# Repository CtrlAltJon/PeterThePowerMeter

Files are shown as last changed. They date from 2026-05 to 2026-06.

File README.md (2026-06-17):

# ⚡ Peter The Power Meter
### with ESP8266 and ADS1115

<p align="center">
  <a href="/Images/guide-docs/view2.jpg">
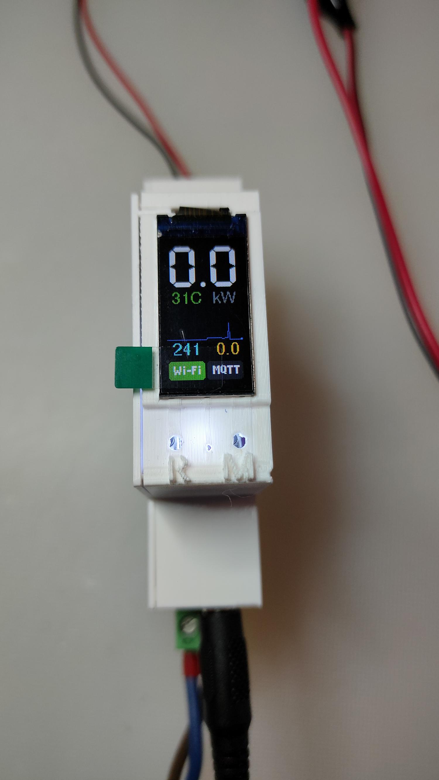
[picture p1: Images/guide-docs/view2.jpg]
Peter the power meter view 2
    
  </a>
</p>

## ⚠️ Disclaimer

> [!CAUTION]
> ### ⚠️ IMPORTANT SAFETY WARNING & DISCLAIMER
> **THIS PROJECT INVOLVES WORKING WITH HIGH VOLTAGE (230VAC). HIGH VOLTAGE CAN CAUSE SEVERE INJURY, ELECTROCUTION, OR DEATH. FIRE HAZARD IS ALSO PRESENT.**
>
> This project is provided "as is", for educational and hobbyist purposes only. By using any part of this project (including hardware designs, PCB layouts, and software), you acknowledge and agree to the following:
>
> * **Assumption of Risk:** You are solely responsible for your own safety and for any damage caused by the assembly, testing, or use of this device.
> * **No Liability:** The author(s) shall not be held liable for any direct or indirect damages, including but not limited to: hardware failure, data loss, property damage (fire, short circuits), personal injury, or death, resulting from the use or misuse of this project.
> * **Assembly & Modification:** Any errors in assembly, soldering (e.g., solder bridges), component selection, firmware modification or others actions are the sole responsibility of the user.
> * **No Warranty:** There is no guarantee regarding the accuracy of measurements, the stability of the software, or the safety of the hardware design for long-term use.
> * **Local Standards:** It is the user's responsibility to ensure that the device complies with local electrical codes and safety regulations.
>
> **IF YOU ARE NOT EXPERIENCED IN WORKING WITH MAINS VOLTAGE, DO NOT ATTEMPT TO BUILD THIS PROJECT.**

## 📜 Revision History
* **00:** First release (30/05/2026)
* **01:** Hardware optimizations and professional safety compliance updates (17/06/2026)
  * **Complete 2.5mm High-Voltage Isolation:** Optimized the High Voltage (HV) layout to strictly enforce a minimum 2.5mm track-to-track clearance across the entire mains section. This includes adding physical PCB isolation slots (milling) between R28, R29, F1, and J3 (pin 2), and shifting transformer TR1 along with adjacent resistors slightly upward to eliminate any tight spacings.
  * **Industrial-Grade Reinforced Insulation:** Preserved the robust **8.0mm isolation barrier** natively designed between the HV and Low Voltage (LV) domains. By combining this wide clearance with the new track-to-track optimizations, the board fully satisfies the strict **Reinforced Insulation** requirements of the **IEC/EN 62368-1** standard (aligning with household and industrial appliance safety regulations like IEC 60335-1 / IEC 60730-1), drastically setting this architecture apart from typical, uncertified DIY designs.
  * **Power Rail & Logic Level Optimization:** Removed 1 pin from connector J11 to eliminate the +5VDC routing to the lateral pcb, successfully migrating the CH340C USB-to-Serial subsystem entirely to a +3.3VDC power rail.
  * **Component Reconfiguration:** Rewired pin 4 (V3) of the CH340C directly to the +3.3VDC rail (mandatory for stable 3.3V operation) while retaining C9 in the layout to act as an active power supply decoupling filter instead of a standard bypass to GND.

## 💡 Design Rationale & Project Overview

### 1.1 System Architecture
This project is a Digital Power Meter designed for real-time energy monitoring with acoustic alarm when a threshold is exceeded. The system is engineered to fit within a standard 1-module DIN rail enclosure (roughly the size of a standard miniature circuit breaker), making it ideal for integration into domestic electrical panels.

*Note: At the moment, the 3D design/CAD file for the DIN enclosure is not available. Contributions regarding the design of a suitable enclosure are highly welcome and would be a valuable addition to this project.*

The system architecture is based on the ESP8266 (ESP-12F) microcontroller, leveraging its Wi-Fi capabilities for IoT integration and an ADS1115 to read voltage and current. For system health, an onboard TFPT1206L1002DV temperature sensor is included to monitor the internal thermal conditions of the enclosure.

For local interaction, the device features a 0.96" color LCD display that provides real-time data visualization and configuration menus. Users can navigate through multiple data pages and perform basic setup tasks using a multi-function physical button. Additionally, the system hosts a built-in Web Server, allowing for advanced remote configuration, firmware updates (OTA), and detailed system management via an intuitive Web UI.

The measurement stage utilizes two primary sensors:
* **Voltage Sensing:** Handled via a dedicated voltage transformer ZMPT107-1 (TR1) for galvanic isolation and safety.
* **Current Sensing:** Implemented using the SCT-013 split-core current transformer (clamp meter).

Both sensors provide a 1VAC sinusoidal output. These signals are conditioned via a voltage divider network and sampled by an ADS1115 16-bit ADC, which communicates with the MCU via the I2C protocol.

### 1.2 Hardware Features & User Interface

<p align="center">
  <a href="/Images/guide-docs/view1.jpg">
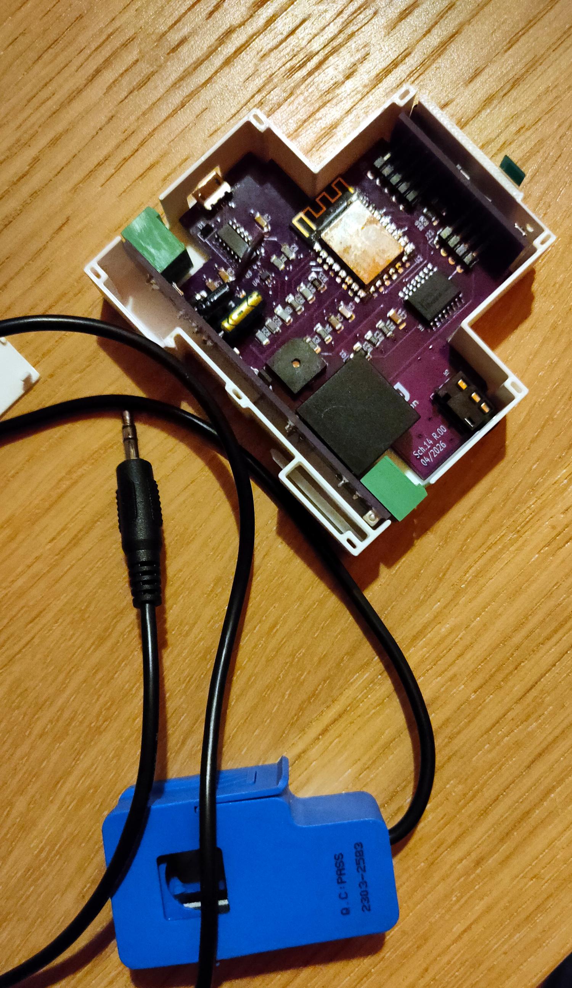
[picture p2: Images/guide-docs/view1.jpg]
Peter the power meter view 1
    
  </a>
</p>

To optimize GPIO usage, a PCF8574 I/O expander is employed for digital signal management and future use. The user interface consists of:
* **Buttons:** A multi-function navigation button (Short press: Page toggle | Long press: Confirm/Action) and a dedicated Pin-hole Hardware Reset button connected directly to Pin 1 (RST) of the ESP8266.
* **Acoustic Feedback:** An active piezoelectric buzzer triggers an audible alarm when a software-defined power threshold is exceeded.
* **Thermal Monitoring:** An onboard TFPT1206L1002DV temperature sensor (PTC thermistor) is integrated into the circuit. This component allows the system to monitor the internal temperature of the enclosure.
* **Display:** A 0.96" Color LCD for local monitoring and basic interaction.
* **Web Server:** A Web User Interface for remote monitoring and full system configuration.

### 1.3 Power Supply & Protection
The device supports 2 power input options and 1 input 230VAC for Voltage reading:

* **Terminal Block (J1):** Accepts a +5VDC regulated supply.

> [!CAUTION]
> **No reverse polarity protection:** This input currently lacks reverse polarity protection; correct orientation is mandatory.

<p align="center">
  <a href="/Images/guide-docs/Guide_J1_Rev-01.png">
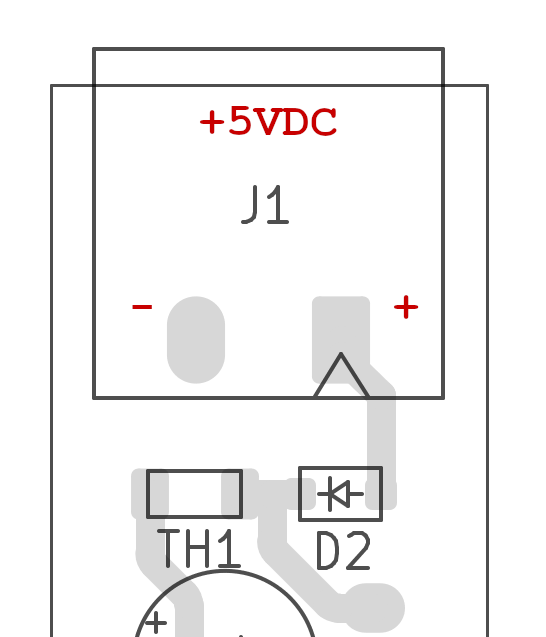
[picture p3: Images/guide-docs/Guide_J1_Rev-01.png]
J1 No reverse polarity protection
    
  </a>
</p>

* **USB Connector (J2):** For secondary power or debugging.
    * *Communication & Debugging:* This interface utilizes a CH340C USB-to-Serial bridge and a UMH3NFHATN transistor pair to communicate with the ESP8266. This setup enables full debugging, serial communication, and firmware programming (automatic reset/bootloader entry).
    * *Safety Feature:* The board implements a dual Schottky diode protection circuit on the positive rails of both J1 and J2. This prevents back-feeding, though it is recommended to disconnect J1 when using USB power.
    * *Overcurrent Protection:* The +5VDC main rail is protected by a MF-NSMF050-2 PTC (Resettable Fuse) rated at 500mA.
* **AC Voltage Input (J3):** High-voltage input for the ZMPT107-1 transformer.
    * *Polarity Recommendation:* Although the transformer operates on AC, it is strictly recommended to respect the Phase (L) and Neutral (N) markings.
    <p align="center">
      <a href="/Images/guide-docs/Guide_J3_Rev-01.png">
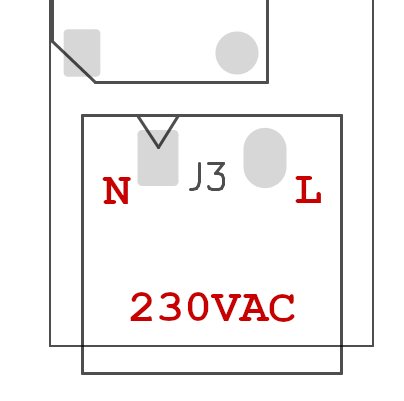
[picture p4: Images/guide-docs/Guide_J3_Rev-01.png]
J3 High-voltage input
        
      </a>
    </p>

    * *Safety Rationale:* The protection fuse is located exclusively on the Phase line. Inverting the polarity would mean that, in the event of a fault or a blown fuse, the Neutral line would be disconnected while the entire internal circuit remains energized (live) through the Phase line. This creates a severe electrocution hazard even when the device appears to be non-functional.
    * *Safety Design:* The circuit features a 250mA T (Slow-blow) fuse placed exclusively on the Phase line. Additionally, the line is equipped with three resistors in series designed to limit the current to 1mA RMS at 230V, providing an essential layer of protection for the sensing stage.

### 1.4 Operational Limits & Grid Compatibility
This device is specifically designed and calibrated for 230VAC/50Hz Phase-Neutral grids (Standard European Grid).

* **Voltage Specificity:** The internal components, including the protection resistors and the ZMPT107-1 transformer ratio, are optimized for 230V. Use with different mains voltages (e.g., 110-120V) may result in inaccurate readings or insufficient signal-to-noise ratio.
* **Frequency Specificity:** The system is tuned for 50Hz operation. While the magnetic components (TR1 and CT) can physically handle 60Hz, the firmware's sampling window and RMS calculation algorithms are optimized for a 20ms period.
* **Warning:** Operation on different grid standards, high-voltage industrial lines, or Phase-to-Phase configurations (without a neutral line) may exceed the safety ratings of the components and the fuse, leading to hardware failure or fire hazard.

## 🌐 2.0 Connectivity & Software Integration
The firmware architecture features a built-in Web Server for real-time monitoring, local configuration, and connections management (Wi-Fi and MQTT). The device natively supports the MQTT protocol for a smart home integration with platforms such as Home Assistant.

### 2.0.1 LCD User Interface (Vertical Orientation)
Navigation is handled via the multi-function button (Short press: Page toggle | Long press: Confirm/Action).

* **Page 1: Real-time Monitor**
    * Power: Current power consumption displayed in kW.
    * Temperature: PCB temperature in °C.
    * Graph: A rolling history graph showing power trends (approx. 1-minute window).
    * Status Badges: Dynamic icons for Wi-Fi connection status and MQTT connection status.
* **Page 2: Power Threshold Configuration**
    * Displays the active alarm threshold (Watts).
    * Allows cyclic adjustment of the new threshold (100W increments) via long-press.
* **Page 3: Voltage Monitoring**
    * Displays the real-time mains voltage (V).
* **Page 4: Acoustic Alarm Settings**
    * Displays and cycles through buzzer modes: Continuous, Slow Intermittent, or Fast Intermittent.
* **Page 5: Save Settings**
    * Summarizes settings. Action: A long-press commits settings to non-volatile memory.
* **Page 6: System Information**
    * Displays network details: Hostname, SSID, IP Address, and Firmware Version.
* **Page 7: System Tools**
    * AP Mode, Reboot device, and Reset (Factory Reset). Requires a long-press with a visual timer-bar.

### 2.0.2 Web Interface & Configuration
The device features a responsive Web UI. Users can connect via browser to the device's IP (visible on LCD page 6).

#### Home Page (Real-Time Dashboard)
* **Connectivity Status:** Dynamic badges for AP Mode, Wi-Fi, and MQTT.
* **Live Telemetry:** Power (W), Voltage (V), Current (A).
* **System Uptime:** Tracks operational time in "Days hh:mm:ss" format.
* **Data Refresh:** Auto-refresh every 10 seconds or manual button.

#### Configuration Page
* **General Settings:** Hostname, Manufacturer, Language (IT/EN), Alarm Threshold, Buzzer Mode.
* **Wi-Fi Setup:** Credentials and IP Assignment (DHCP or Static IP).
* **MQTT Setup (Optional):** Broker IP, Port, and Authentication.
* **Buttons:** Save & Reboot, Reboot, Firmware Update (OTA), Home.

## 🛠️ Manufacturing & Assembly Notes

### 3.0 Hardware Configuration
**ADS1115 I2C Address Selection:** Hardware-defined through two "0-Ohm bridge" resistors: R16 and R17. Only one of these resistors must be populated at a time:
* **R16:** Connects the ADDR pin to +3.3V, ADS1115 Address `0x49`
* **R17:** Connects the ADDR pin to GND, ADS1115 Address `0x48` (Default).

**Safety Design:** To prevent assembly errors, the PCB layout utilizes a shared common pad for both R16 and R17. This physical constraint makes it nearly impossible to populate both resistors simultaneously, effectively protecting the +3.3V rail from a direct short circuit to Ground. However, be careful when assembling.

## Assembly Layout: TOP Layer
<p align="center">
  <a href="/Images/guide-docs/Guide_Assembly-Top_Rev-01.png">
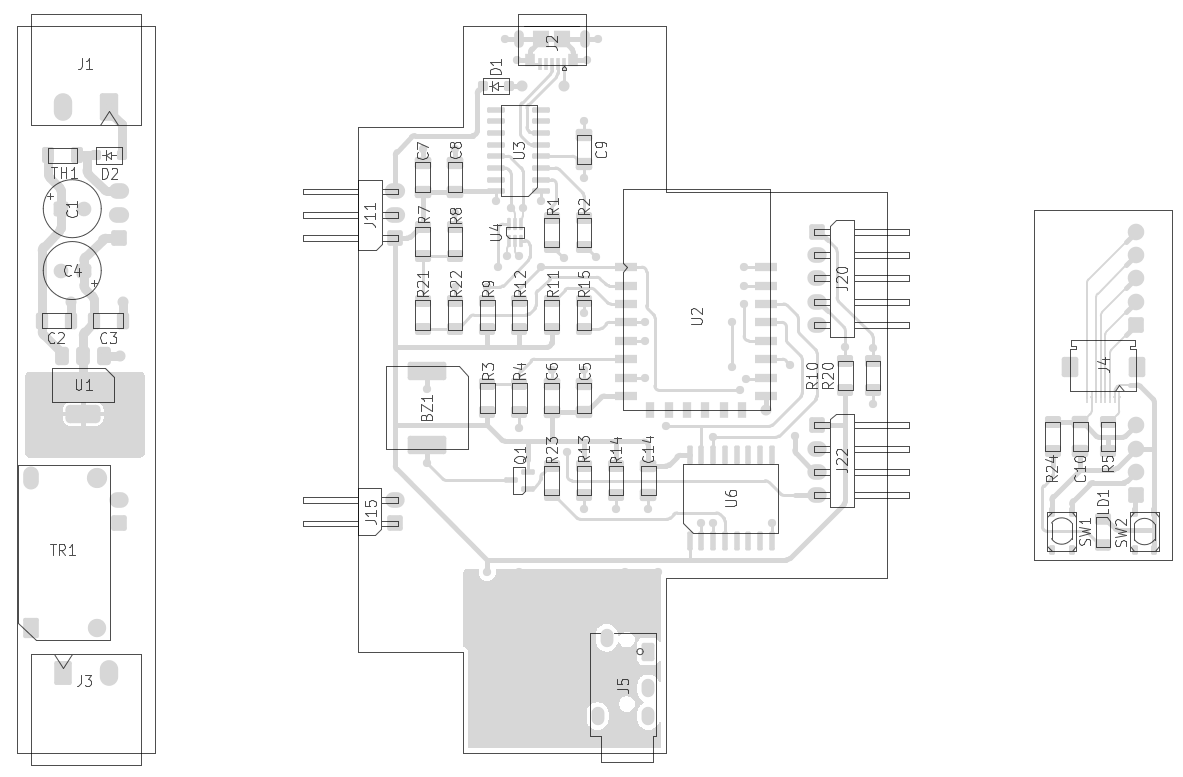
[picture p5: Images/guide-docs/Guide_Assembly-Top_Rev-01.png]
Assembly Layout Top
    
  </a>
</p>

## Assembly Layout: BOTTOM Layer
<p align="center">
  <a href="/Images/guide-docs/Guide_Assembly-Bottom_Rev-01.png">
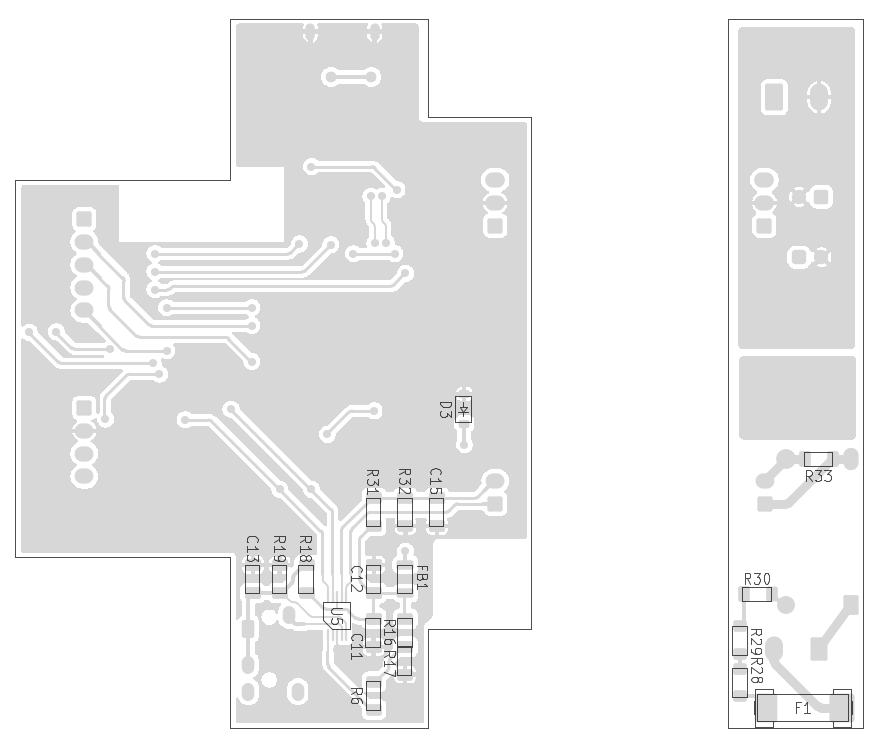
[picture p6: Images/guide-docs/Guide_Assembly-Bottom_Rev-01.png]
Assembly Layout Bottom
    
  </a>
</p>

## Dimensions
<p align="center">
  <a href="/Images/guide-docs/Guide_Dimensions_Rev-01.png">
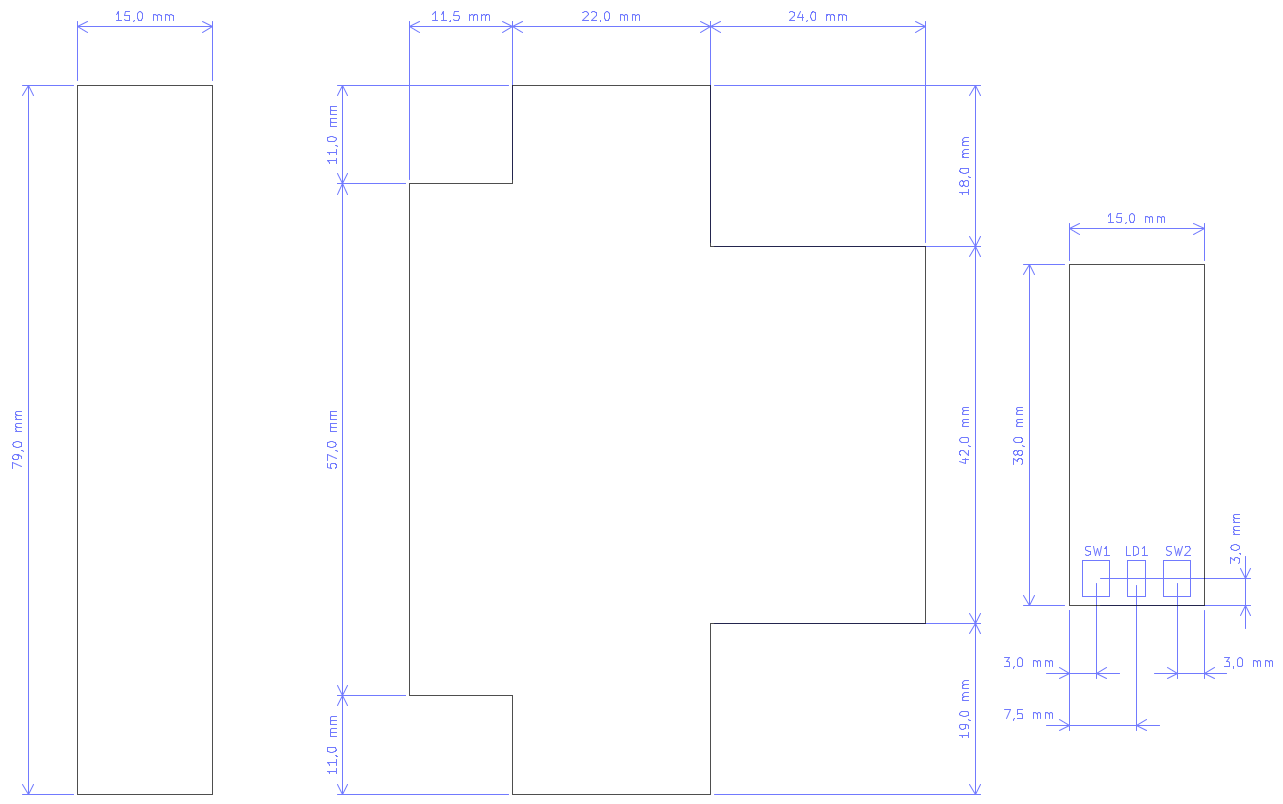
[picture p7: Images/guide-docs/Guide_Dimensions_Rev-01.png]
Dimensions
    
  </a>
</p>

## 💻 4.0 Firmware
Peter The Power Meter has an embedded firmware designed for real-time single-phase energy monitoring. The system samples AC voltage and current waveforms, calculates Root Mean Square (RMS) values and active power consumption, provides a multi-page visual interface on a TFT display, and integrates with home automation systems via the MQTT protocol.

### Technical Specifications
* **Language:** C++ (Standard C++11/14).
* **Framework:** Arduino Core for ESP8266.
* **Development Environment:** PlatformIO.
* **Core Hardware:** Espressif ESP8266 (e.g., Wemos D1 Mini).
* **Data Acquisition:** External ADS1115 16-bit ADC connected via I2C for high-precision differential sampling.
* **Sensor Support:** Current Transformers (SCT-013), Voltage Transformers (ZMPT107-1), and PTC temperature sensors (TFPT1206).

### Key Features
* **High-Speed Sampling & RMS Calculation:** Performs rapid sampling of sinusoidal signals to calculate precise Voltage RMS, Current RMS, and Active Power (W) over a sliding 1-second window.
* **Display Management:** Features a multi-page User Interface on an ST7735 (0.96" TFT) display; includes real-time power trend graphs, connectivity status badges, and system information pages.
* **IoT & Home Automation:**
    * **MQTT Telemetry:** Transmits energy data using a time-weighted average calculated over the publishing interval (default 20s).
    * **Home Assistant Integration:** Fully supports Auto-Discovery, automatically creating sensors and configuration entities (Select/Number) within Home Assistant.
* **Embedded Web Server:** A built-in web portal protected by HTTP Basic Authentication allows users to configure WiFi credentials, MQTT settings, alarm thresholds, and perform fine sensor calibration (offset and scale).
* **Alarm System:** Manages a buzzer via a PCF8574 I/O expander with programmable modes (Continuous, Slow Pulse, Fast Pulse) triggered when power exceeds a user-defined threshold.
* **Reliability & Maintenance:**
    * **Resilient Connectivity:** Implements an exponential backoff strategy for WiFi and MQTT reconnection.
    * **OTA Updates:** Supports Over-The-Air firmware updates through the web interface.
    * **Localization:** Built-in multi-language support (English and Italian) using PROGMEM to optimize RAM usage.

### 4.0.1 Sensor Calibration & Physics Guide (include/config.h)
The following constants define how the raw electrical signals from the sensors are translated into human-readable values (Amps, Volts, Watts).

#### Current Conversion (FACTOR_A_V)
* **Description:** This is the scaling factor for the Current Transformer (CT). It converts the voltage measured by the ADC into RMS Amperes.
* **Formula:** `I_RMS = V_ADC * FACTOR_A_V`.
* **Configuration:** The `FACTOR_A_V` of 25.0f is set based on the characteristics of the SCT-013 current transformer.
* **When to change:**
    1. You replace the SCT-013 with a model that has a different Current/Voltage ratio (e.g., 30A/1V or 100A/50mA).
    2. You add or change an external burden resistor in parallel with the CT output.

#### Voltage Conversion (FACTOR_V_V)
* **Description:** This factor scales the low-voltage signal from the ZMPT107-1 transformer back to the actual grid voltage.
* **Formula:** `V_Grid = V_ADC * FACTOR_V_V`.
* **Configuration:** The `FACTOR_V_V` of 246.0f is derived directly from the ratio of the primary resistance (246KΩ) to the burden resistance (1KΩ).
* **When to change:** If you modify the scaling "divider" (e.g., changing series resistors on the Primary side or the burden resistor on the Secondary side).

#### ADC Precision & Sampling Rate
* **ADC Precision:** `ADS_GAIN` (GAIN_TWO) sets the full-scale range to ±2.048V, with an `ADS_MULTIPLIER` of 0.0000625.
* **Sampling Rate:** 860 Samples Per Second is the maximum stable rate for the ADS1115 and provides high fidelity for power calculations.

#### Noise, Safety, and Temperature
* **CURRENT_NOISE_FLOOR (0.002f):** A software filter that forces the current to 0.0A if the measured voltage is below 2mV.
* **VOLTAGE_MIN_THRESHOLD (50.0f):** If the measured voltage is below 50V, the system assumes the sensor is faulty and falls back to 230V.
* **Temperature Monitoring:** The firmware averages 10 readings (`PTC_AVG_SAMPLES`) to stabilize the PTC sensor data; if the temperature exceeds `TEMP_WARNING_THRESHOLD` (45.0°C), the display text turns RED.

| Constant | Default Value | Unit | Description |
| :--- | :--- | :--- | :--- |
| FACTOR_A_V | 25.0 | A/V | Ratio of Amps per Volt from the CT circuit. |
| FACTOR_V_V | 246.0 | V/V | Ratio of Grid Volts per Volt from the VT circuit. |
| ADS_GAIN | GAIN_TWO | - | Sets ADC input range to ±2.048V. |
| ADS_SPS | 860 | Hz | Samples taken per second from the AC wave. |
| CURRENT_NOISE_FLOOR | 0.002 | V | Minimum voltage to consider a valid current reading. |
| VOLTAGE_MIN_THRESHOLD | 50.0 | V | Voltage below which the system uses a fallback value. |

### 4.0.2 Per-device calibration limits (include/config.h)
These constants define the acceptable range and default values for the calibration parameters stored in EEPROM.

* **Scale Factors:** `CAL_SCALE_DEFAULT` is 1.0f (no correction), with a range between 0.1f and 10.0f.
* **Voltage Offset Limits:** -500.0f to 500.0f Volts.
* **Current Offset Limits:** -100.0f to 100.0f Amperes.
* **Temperature Offset Limits:** -50.0f to 50.0f degrees Celsius.

| Constant | Default/Range | Unit | Description |
| :--- | :--- | :--- | :--- |
| CAL_SCALE_DEFAULT | 1.0f | - | Default multiplicative scale factor. |
| CAL_SCALE_MIN | 0.1f | - | Minimum allowed value for scale factors. |
| CAL_SCALE_MAX | 10.0f | - | Maximum allowed value for scale factors. |
| CAL_OFFSET_V_MIN | -500.0f | V | Minimum allowed voltage offset. |
| CAL_OFFSET_V_MAX | 500.0f | V | Maximum allowed voltage offset. |
| CAL_OFFSET_A_MIN | -100.0f | A | Minimum allowed current offset. |
| CAL_OFFSET_A_MAX | 100.0f | A | Maximum allowed current offset. |
| CAL_OFFSET_TEMP_MIN | -50.0f | °C | Minimum allowed temperature offset. |
| CAL_OFFSET_TEMP_MAX | 50.0f | °C | Maximum allowed temperature offset. |

### 4.0.3 PTC Calibration & Hardware (include/config.h)
The device monitors internal temperature using the TFPT1206 series PTC sensor.

* **PTC_V_SOURCE:** 3.3f (Standard logic voltage).
* **PTC_R_PULLUP:** 33,000 Ω (Fixed resistor R7).
* **ADC Compensation:** Constants `PTC_R_DIVIDER_TOTAL` and `PTC_R_DIVIDER_LOAD` compensate for the voltage divider on the ESP8266 ADC input stage.
* **Sensor Characteristics:** `PTC_NOMINAL_RES` (10,000 Ω at 25°C) and `PTC_COEFF` (0.00411) define the resistance-to-temperature curve.

| Constant | Default Value | Unit | Description |
| :--- | :--- | :--- | :--- |
| PTC_V_SOURCE | 3.3 | V | Logic source voltage for the sensing branch. |
| PTC_R_PULLUP | 33,000 | Ω | Fixed pull-up resistor ($R_7$) in the divider. |
| PTC_NOMINAL_RES | 10,000 | Ω | PTC resistance at 25°C. |
| PTC_COEFF | 0.00411 | - | TCR (Temperature Coefficient) of the sensor. |
| PTC_R_DIVIDER_TOTAL | 100,220 | Ω | ADC input stage total resistance ($R_{21} + R_{22}$). |

## 🤝 Contributing

Contributions, issues, and feature requests are welcome!
Feel free to [open an issue](https://github.com/CtrlAltJon/PeterThePowerMeter/issues) or submit a pull request.

## 🔜 Coming Soon
I am currently in the process of refining and cleaning up the firmware comments to ensure the code is as clear and readable as possible, even though the project is fully functional.
I am also polishing the documentation and preparing additional guides that I'll upload to the repository soon.
Currently seeking help with:
* Enclosure Design: I'm looking for contributors to design a 3D-printable enclosure compatible with a standard 1-module DIN rail format. I think I'll be able to upload at least the STL file soon, but not the project.

## 📝 License

This project is licensed under the MIT License. See the [LICENSE](LICENSE) file for details.

## 👤 Author

CtrlAltJon

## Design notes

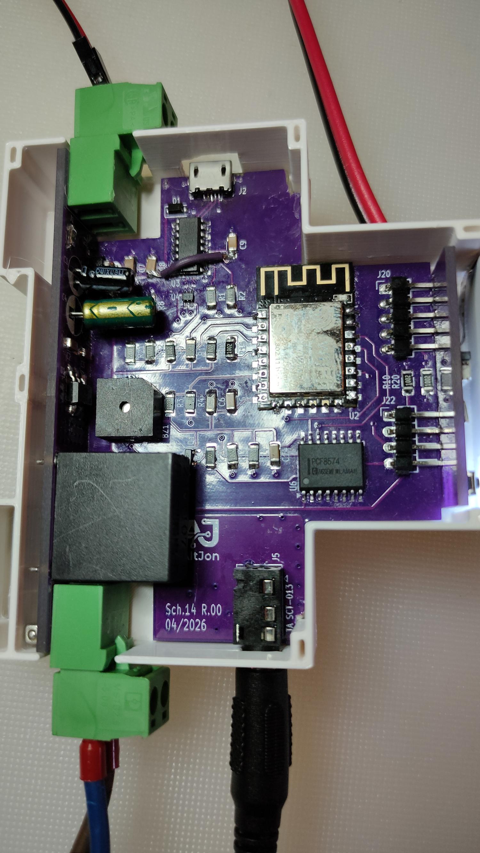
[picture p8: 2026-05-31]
Images/hardware/peter-hw-01.jpg

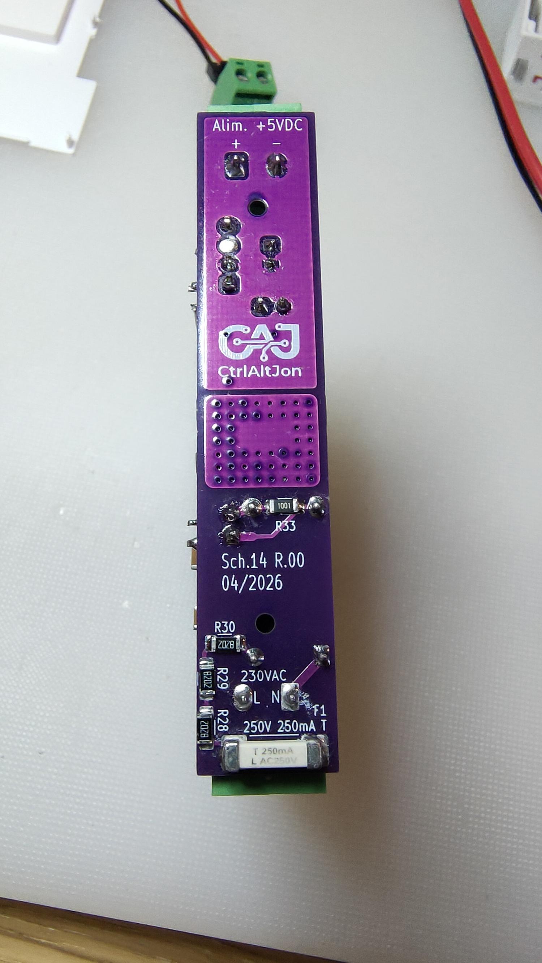
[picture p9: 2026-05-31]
Images/hardware/peter-hw-06.jpg

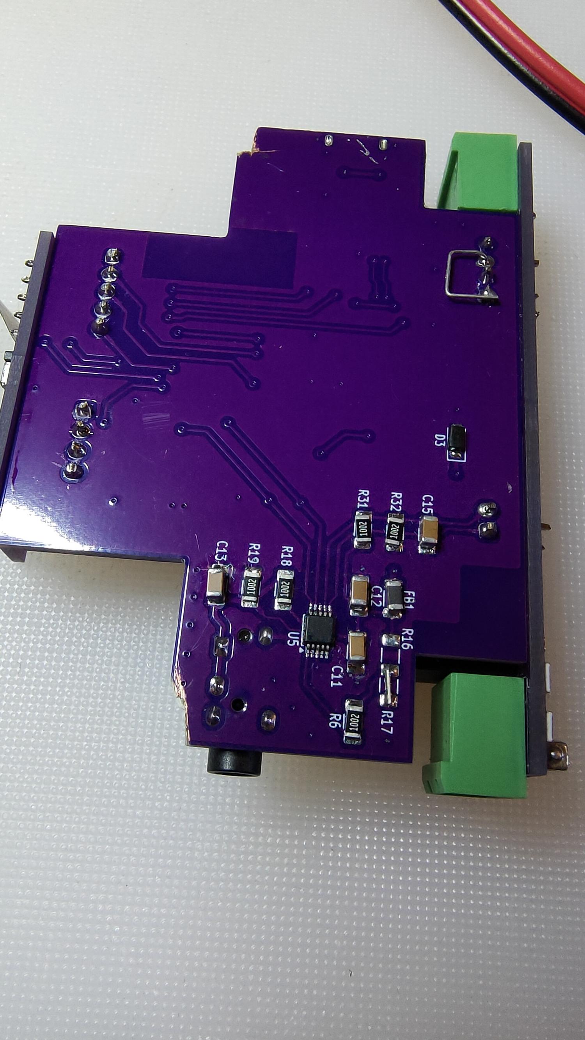
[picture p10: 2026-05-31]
Images/hardware/peter-hw-08.jpg

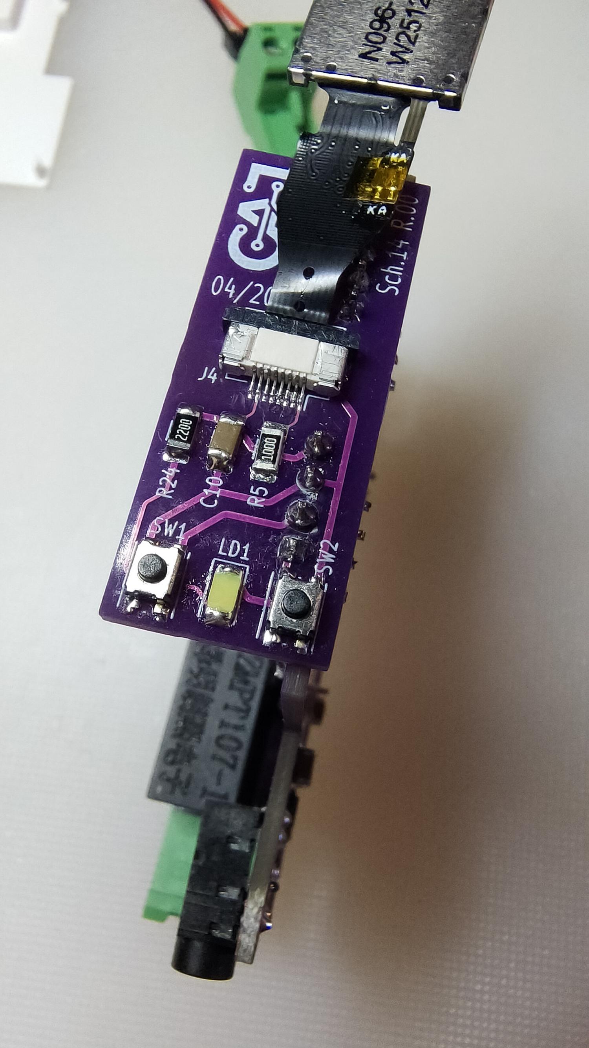
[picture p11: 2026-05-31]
Images/hardware/peter-hw-05.jpg

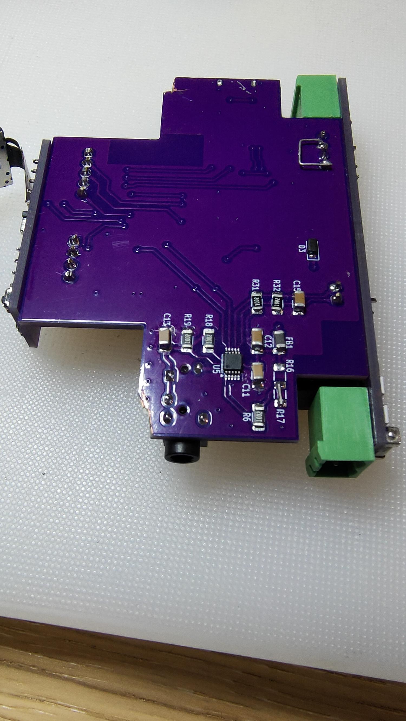
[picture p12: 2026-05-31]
Images/hardware/peter-hw-02.jpg

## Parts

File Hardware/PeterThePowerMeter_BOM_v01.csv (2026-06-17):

Comment | Designator | Footprint | LCSC | Quantity
0 | R16,R17 | R_1206_3216Metric_Pad1.30x1.75mm_HandSolder | C137394 | 2
100K | R22 | R_1206_3216Metric_Pad1.30x1.75mm_HandSolder | C844863 | 1
100R | R5 | R_1206_3216Metric_Pad1.30x1.75mm_HandSolder | C137392 | 1
100nF | C11,C14,C2,C3,C5,C8,C9 | C_1206_3216Metric_Pad1.33x1.80mm_HandSolder | C2167356 | 7
100uF | C4 | CP_Radial_D6.3mm_P2.50mm | C1589590 | 1
10K | R10,R11,R12,R13,R14,R15,R18,R19,R20,R3,R31,R32,R6,R9 | R_1206_3216Metric_Pad1.30x1.75mm_HandSolder | C132649 | 14
10uF | C12,C13,C15,C7 | C_1206_3216Metric_Pad1.33x1.80mm_HandSolder | C89632 | 4
1K | R23,R24,R33 | R_1206_3216Metric_Pad1.30x1.75mm_HandSolder | C131398 | 3
1N4007W | D3 | D_SOD-123 | C3018540 | 1
220 | R21 | R_1206_3216Metric_Pad1.30x1.75mm_HandSolder | C137353 | 1
22uF | C10,C6 | C_1206_3216Metric_Pad1.33x1.80mm_HandSolder | C318754 | 2
3.2x4.2 | SW1 | SW_Push_1P1T_NO_Vertical_Wuerth_434133025816 | C470426 | 1
330 | R4 | R_1206_3216Metric_Pad1.30x1.75mm_HandSolder | C114944 | 1
33K | R7 | R_1206_3216Metric_Pad1.30x1.75mm_HandSolder | C7233588 | 1
434133025816 | SW2 | SW_Push_1P1T_NO_Vertical_Wuerth_434133025816 | C470426 | 1
470R | R1,R2 | R_1206_3216Metric_Pad1.30x1.75mm_HandSolder | C844876 | 2
47uF | C1 | CP_Radial_D6.3mm_P2.50mm | C1580807 | 1
82K | R28,R29,R30 | R_1206_3216Metric_Pad1.30x1.75mm_HandSolder | C870906 | 3
ADS1115IDGS | U5 | TSSOP-10_3x3mm_P0.5mm | C37593 | 1
BC807-40 | Q1 | SOT-23 | C5184433 | 1
CH340C | U3 | SOIC-16_3.9x9.9mm_P1.27mm | C84681 | 1
ESP-12F | U2 | ESP-12E | C82891 | 1
LD1117S33TR | U1 | SOT-223-3_TabPin2 | C86781 | 1
LED | LD1 | LED_1206_3216Metric | C133134 | 1
MF-NSMF050-2 | TH1 | R_1206_3216Metric_Pad1.30x1.75mm_HandSolder | C75464 | 1
MH3261-601Y | FB1 | L_1206_3216Metric | C840591 | 1
PCF8574 | U6 | SOIC-16W_7.5x10.3mm_P1.27mm | C7605 | 1
PJ320E | J5 | Jack_3.5mm_PJ320E_Horizontal | C2939183 | 1
PMEG2010AEH-115 | D1,D2 | D_SOD-123F | C110921 | 2
SMD9650-DC3V | BZ1 | Buzzer_CUI_CPT-9019S-SMT | C49246960 | 1
Schurter UMT250 3403.0160.24 | F1 | Fuse_Schurter_UMZ250 | C3163460 | 1
Screw_Terminal_01x02 | J1,J3 | PhoenixContact_MSTBA_2,5_2-G_1x02_P5.00mm_Horizontal | C90074 | 2
TFPT1206L1002DV | R8 | R_1206_3216Metric_Pad1.30x1.75mm_HandSolder | C2154230 | 1
UMH3NFHATN | U4 | SOT-363_SC-70-6 | C3194552 | 1
USB3076-30-A | J2 | USB_Micro-B_GCT_USB3076-30-A | C6007475 | 1
ZMPT107-1 | TR1 | Transformer_Zeming_ZMPT107 | C125191 | 1

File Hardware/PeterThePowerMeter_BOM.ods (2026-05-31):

Id | Reference | Footprint | Value | Code | Descrizione
1 | R7 | R_1206_3216Metric_Pad1.30x1.75mm_HandSolder | 33K
2 | C5,C2,C3,C8, C14,C9,C11 | C_1206_3216Metric_Pad1.33x1.80mm_HandSolder | 100nF | C1206C104J5RACTU | MLCC 100nF X7R ±5% 50V 1206 Ceramic Capacitors
3 | R22 | R_1206_3216Metric_Pad1.30x1.75mm_HandSolder | 100K
4 | D1,D2 | D_SOD-123F | PMEG2010AEH-115 | PMEG2010AEH,115 | Diode Shottky 1 Independent 20V 1A Surface Mount SOD-123F
5 | R2,R1 | R_1206_3216Metric_Pad1.30x1.75mm_HandSolder | 470R
6 | TR1 | Transformer_Zeming_ZMPT107 | ZMPT107-1 | ZMPT107-1 | 2mA 1:1 Voltag Sense Transformer Through Hole
7 | U2 | ESP-12E | ESP-12F | ESP-12F
8 | U3 | SOIC-16_3.9x9.9mm_P1.27mm | CH340C | CH340C | USB to UART 2Mbps USB 2.0 SOP-16 Interface Controllers
9 | J4 | Hirose_FH12-8S-0.5SH_1x08-1MP_P0.50mm_Horizontal | Conn_01x08_Socket | FH12-8S-0.5SH(55) | FFC/FPC Connector 8 Position 0.5mm Pitch Bottom Contact Surface Mount, Right Angle -40℃~+85℃
10 | J15 | PinHeader_1x02_P2.54mm_Horizontal | Conn_01x02_Pin
11 | J22,J11 | PinHeader_1x04_P2.54mm_Horizontal | Conn_01x04_Male
12 | U4 | SOT-363_SC-70-6 | UMH3NFHATN |  | Pre-Biased Bipolar Transistor (BJT) 50Vce 100mA 150mW Surface Mount SOT-363
13 | R24 | R_1206_3216Metric_Pad1.30x1.75mm_HandSolder | 120R
14 | U1 | SOT-223-3_TabPin2 | LD1117S33TR |  | 800mA Fixed Low Drop Positive Voltage Regulator, Fixed Output 3.3V, SOT-223
16 | Q1 | SOT-23 | BC807-40 |  | 0.8A Ic, 45V Vce, PNP Transistor, SOT-23
17 | C10,C6 | C_1206_3216Metric_Pad1.33x1.80mm_HandSolder | 22uF | CL31A226KOCLNNC | 22uF ±10% 16V Ceramic Capacitor X5R 1206
18 | R11,R20,R14, R9,R10,R3, R15,R12,R13, R31,R32,R6, R18,R19 | R_1206_3216Metric_Pad1.30x1.75mm_HandSolder | 10K
19 | R23,R33 | R_1206_3216Metric_Pad1.30x1.75mm_HandSolder | 1K
20 | J3,J1 | PhoenixContact_MSTBA_2,5_2-G_1x02_P5.00mm_Horizontal | Screw_Terminal_01x02 | 1757242 | 2 Position Board Side/Socket - Closed 5.08mm Pitch Right-Angle Pin
 |  | External Plug Phoenix Contact for cable |  | 1757019 | 2 Position Plug 5.08mm Pitch
21 | BZ1 | Buzzer_CUI_CPT-9019S-SMT | SMD9650-DC3V |  | Active 3kHz Piezoelectric 3V SMD,D9.6xL5mm
22 | C4 | CP_Radial_D6.3mm_P2.50mm | 100uF |  | Electrolytic Capacitor
24 | R21 | R_1206_3216Metric_Pad1.30x1.75mm_HandSolder | 220R
25 | LD1 | LED_1206_3216Metric | LED
26 | SW1,SW2 | SW_Push_1P1T_NO_Vertical_Wuerth_434133025816 | 3.2x4.2 HX 3x4x2-2P-1.6N | 434133025816 | WS-TASV SMT Tactile Switches 2.5mm 160g 50mA 16V Black
 |  |  |  |  | 2 Alternative codes present in LCSC.com SKRPANE010 and C49234124
27 | R5 | R_1206_3216Metric_Pad1.30x1.75mm_HandSolder | 100R
28 | R4 | R_1206_3216Metric_Pad1.30x1.75mm_HandSolder | 330R
29 | R8 | R_1206_3216Metric_Pad1.30x1.75mm_HandSolder | TFPT1206L1002DV |  | 125mW 10kΩ 1206 PTC Thermistors
30 | C7,C12,C15, C13 | C_1206_3216Metric_Pad1.33x1.80mm_HandSolder | 10uF | CL31B106KBHNNNE | CAP CER MLCC 10uF 50V X7R 1206
31 | J2 | USB_Micro-B_GCT_USB3076-30-A | USB3076-30-A |  | USB 2.0 1 5P -30℃~+85℃ USB, DVI, HDMI Connector Assemblies RoHS
32 | TH1 | R_1206_3216Metric_Pad1.30x1.75mm_HandSolder | MF-NSMF050-2 |  | 13.2V 500mA 100A 1A 150mΩ 1206 PTC Resettable Fuses RoHS
33 | J20 | PinHeader_1x05_P2.54mm_Horizontal | Conn_01x05_Pin
34 | U6 | SOIC-16W_7.5x10.3mm_P1.27mm | PCF8574 | PCF8574T/TR | Remote 8-bit I/O expander for I2C-bus
35 | C1 | CP_Radial_D6.3mm_P2.50mm | 47uF |  | Electrolytic Capacitor
36 | J5 | Jack_3.5mm_PJ320E_Horizontal | PJ320E |  | Audio Jack, 4 Poles (TRRS)
39 | R29,R30,R28 | R_1206_3216Metric_Pad1.30x1.75mm_HandSolder | 82K | RT1206BRD0782KL | Thin Film Resistors - SMD 1/4W 82K ohm .1% 25p pm 250V
40 | R16,R17 | R_1206_3216Metric_Pad1.30x1.75mm_HandSolder | 0R |  | Bridge 0 Ohm 1206
42 | D3 | D_SOD-123 | 1N4007W | C3018540 | Diode 1kV 1A Surface Mount SOD-123
44 | U5 | TSSOP-10_3x3mm_P0.5mm | ADS1115IDGS |  | Ultra-Small, Low-Power, I2C-Compatible, 860-SPS, 16-Bit ADCs With Internal Reference, Oscillator, and Programmable Comparator, VSSOP-10
45 | F1 | Fuse_Schurter_UMZ250 | Schurter UMT250 | 3403.0160.24 | SMD Fuse UMT 250 10mm x 3mm
46 | FB1 | L_1206_3216Metric | MH3261-601Y |  | 600Ω@100MHz 1 Line Ferrite Bead 1206 2A 100mΩ
 | LCD | Graphic 80BGRx160 Dot-matrix 0.96 inch ST7735 TFT Screen | N096-1608TBBIG09-C08

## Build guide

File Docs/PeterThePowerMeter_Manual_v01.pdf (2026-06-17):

# POWER METER

with ESP8266 and ADS1115

Last update, 17/06/2026

### Disclaimer

### ⚠️ IMPORTANT SAFETY WARNING & DISCLAIMER

THIS PROJECT INVOLVES WORKING WITH HIGH VOLTAGE (230VAC). HIGH VOLTAGE CAN CAUSE SEVERE INJURY, ELECTROCUTION, OR DEATH. FIRE HAZARD IS ALSO PRESENT.

This project is provided "as is", for educational and hobbyist purposes only. By using any part of this project (including hardware designs, PCB layouts, and software), you acknowledge and agree to the following:
1.Assumption of Risk: You are solely responsible for your own safety and for any damage caused by the assembly, testing, or use of this device. 2.No Liability: The author(s) shall not be held liable for any direct or indirect damages, including but not limited to: hardware failure, data loss, property damage (fire, short circuits), personal injury, or death, resulting from the use or misuse of this project.
3.Assembly & Modification: Any errors in assembly, soldering (e.g., solder bridges), component selection, firmware modification or others actions are the sole responsibility of the user.
4.No Warranty: There is no guarantee regarding the accuracy of measurements, the stability of the software, or the safety of the hardware design for long-term use.
5.Local Standards: It is the user's responsibility to ensure that the device complies with local electrical codes and safety regulations. IF YOU ARE NOT EXPERIENCED IN WORKING WITH MAINS VOLTAGE, DO NOT ATTEMPT TO BUILD THIS PROJECT.

### Revision History

- 00: First release (30/05/2026)
- 01: Hardware optimizations and professional safety compliance updates (17/06/2026)
- Complete 2.5mm High-Voltage Isolation: Optimized the High Voltage (HV) layout to strictly enforce a minimum 2.5mm track-to-track clearance across the entire mains section. This includes adding physical PCB isolation slots (milling) between R28, R29, F1, and J3 (pin 2), and shifting transformer TR1 along with adjacent resistors slightly upward to eliminate any tight spacings.
- Industrial-Grade Reinforced Insulation: Preserved the robust 8.0mm isolation barrier natively designed between the HV and Low Voltage (LV) domains. By combining this wide clearance with the new track-to-track optimizations, the board fully satisfies the strict Reinforced Insulation requirements of the IEC/EN 62368-1 standard (aligning with household and industrial appliance safety regulations like IEC 60335-1 / IEC 60730-1), drastically setting this architecture apart from typical, uncertified DIY designs.
- Power Rail & Logic Level Optimization: Removed 1 pin from connector J11 to eliminate the +5VDC routing to the lateral pcb, successfully migrating the CH340C USB-to-Serial subsystem entirely to a +3.3VDC power rail.
- Component Reconfiguration: Rewired pin 4 (V3) of the CH340C directly to the +3.3VDC rail (mandatory for stable 3.3V operation) while retaining C9 in the layout to act as an active power supply decoupling filter instead of a standard bypass to GND.

### Design Rationale & Project Overview

### 1.1 System Architecture

This project is a Digital Power Meter designed for real-time energy monitoring with acoustic alarm when a threshold is exceeded. The system is engineered to fit within a standard 1-module DIN rail enclosure (roughly the size of a standard miniature circuit breaker), making it ideal for integration into domestic electrical panels.

At the moment, the 3D design/CAD file for the DIN enclosure is not available. Contributions regarding the design of a suitable enclosure are highly welcome and would be a valuable addition to this project.

The system architecture is based on the ESP8266 (ESP-12F) microcontroller, leveraging its Wi-Fi capabilities for IoT integration and an ADS1115 to read voltage and current. For system health, an onboard TFPT1206L1002DV temperature sensor is included to monitor the internal thermal conditions of the enclosure.
For local interaction, the device features a 0.96" color LCD display that provides real-time data visualization and configuration menus. Users can navigate through multiple data pages and perform basic setup tasks using a multi-function physical button. Additionally, the system hosts a built-in Web Server, allowing for advanced remote configuration, firmware updates (OTA), and detailed system management via an intuitive Web UI.

The measurement stage utilizes two primary sensors:
- Voltage Sensing: Handled via a dedicated voltage transformer ZMPT107-1 (TR1) for galvanic isolation and safety.
- Current Sensing: Implemented using the SCT-013 split-core current transformer (clamp meter).
Both sensors provide a 1VAC sinusoidal output. These signals are conditioned via a voltage divider network and sampled by an ADS1115 16-bit ADC, which communicates with the MCU via the I2C protocol.

### 1.2 Hardware Features & User Interface

To optimize GPIO usage, a PCF8574 I/O expander is employed for digital signal management and future use. The user interface consists of:
- Buttons: A multi-function navigation button (Short press: Page toggle | Long press: Confirm/Action) and a dedicated Pin-hole Hardware Reset
button connected directly to Pin 1 (RST) of the ESP8266.
- Acoustic Feedback: An active piezoelectric buzzer triggers an audible alarm when a software-defined power threshold is exceeded.
- Thermal Monitoring: An onboard TFPT1206L1002DV temperature sensor (PTC thermistor) is integrated into the circuit. This component allows the system to monitor the internal temperature of the enclosure.
- Display: A 0.96" Color LCD for local monitoring and basic interaction.
- Web Server: A Web User Interface for remote monitoring and full system configuration.

### 1.3 Power Supply & Protection

The device supports 2 power input options and 1 input 230VAC for Voltage reading:
1.Terminal Block (J1): Accepts a +5VDC regulated supply.
- Warning - No reverse polarity protection:
This input currently lacks reverse polarity protection; correct orientation is mandatory.

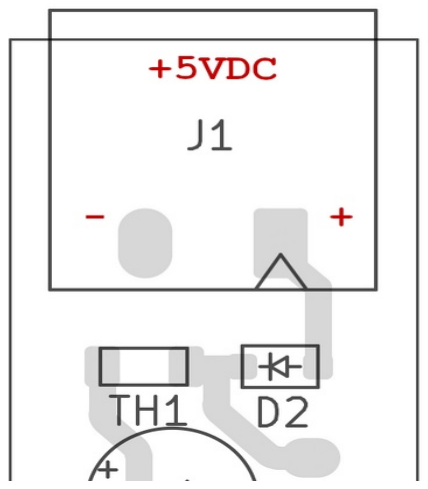
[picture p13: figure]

2.USB Connector (J2): For secondary power or debugging.
- Communication & Debugging: This interface utilizes a CH340C USB-to-Serial bridge and a UMH3NFHATN transistor pair to communicate with the ESP8266. This setup enables full debugging, serial communication, and firmware programming (automatic reset/bootloader entry).

- Safety Feature: The board implements a dual Schottky diode protection circuit on the positive rails of both J1 and J2. This prevents back-feeding, though it is recommended to disconnect J1 when using USB power.
- Overcurrent Protection: The +5VDC main rail is protected by a MF-NSMF050-2 PTC (Resettable Fuse) rated at 500mA.
3.AC Voltage Input (J3): High-voltage input for the ZMPT107-1 transformer.
- Polarity Recommendation: Although the transformer operates on AC, it is strictly recommended to respect the Phase (L) and Neutral
(N) markings.

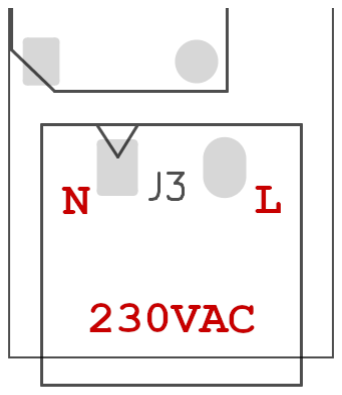
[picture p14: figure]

- Safety Rationale: The protection fuse is located exclusively on the Phase line. Inverting the polarity would mean that, in the event of a fault or a blown fuse, the Neutral line would be disconnected while the entire internal circuit remains energized (live) through the Phase line. This creates a severe electrocution hazard even when the device appears to be non-functional.
- Safety Design: The circuit features a 250mA T (Slow-blow) fuse placed exclusively on the Phase line. Additionally, the line is equipped with three resistors in series designed to limit the current to 1mA RMS at 230V, providing an essential layer of protection for the sensing stage.

### 1.4 Operational Limits & Grid Compatibility

This device is specifically designed and calibrated for 230VAC/50Hz Phase-Neutral grids (Standard European Grid).
- Voltage Specificity: The internal components, including the protection resistors and the ZMPT107-1 transformer ratio, are optimized for 230V. Use with different mains voltages (e.g., 110-120V) may result in inaccurate readings or insufficient signal-to-noise ratio.
- Frequency Specificity: The system is tuned for 50Hz operation. While the magnetic components (TR1 and CT) can physically handle 60Hz, the firmware's sampling window and RMS calculation algorithms are optimized for a 20ms period.
- Warning: Operation on different grid standards, high-voltage industrial lines, or Phase-to-Phase configurations (without a neutral line) may exceed the safety ratings of the components and the fuse, leading to hardware failure or fire hazard.

### 2.0 Connectivity & Software Integration

The firmware architecture features a built-in Web Server for real-time monitoring, local configuration, and connections management (Wi-Fi and MQTT). The device natively supports the MQTT protocol for a smart home integration with platforms such as Home Assistant.

### 2.0.1 LCD User Interface (Vertical Orientation)

The 0.96" display provides a multi-page interface for local data visualization and system control. Navigation is handled via the multi-
function button (Short press: Page toggle | Long press: Confirm/Action).
- Page 1: Real-time Monitor
- Power: Current power consumption displayed in kW.
- Temperature: PCB temperature in °C.
- Graph: A rolling history graph showing power trends (approx. 1-minute window).
- Status Badges: Dynamic icons for Wi-Fi connection status (Green:
Connected | Blue: Access Point Mode) and MQTT connection status
(Green: Connected to server | Grey: Disconnected from server).
- Page 2: Power Threshold Configuration
- Displays the active alarm threshold (Watts).
- Allows cyclic adjustment of the new threshold (100W increments) via long-press. The value wraps around to zero once the upper limit is reached.
- Page 3: Voltage Monitoring
- Displays the real-time mains voltage (V) as measured by the ZMPT107-1 transformer.
- Page 4: Acoustic Alarm Settings
- Displays the current buzzer mode: Continuous, Slow Intermittent, or Fast Intermittent.
- Users can cycle through these modes via long-press.
- Page 5: Save Settings
- Summarizes the current threshold and buzzer configurations.
- Action: A long-press commits these settings to non-volatile memory. Note: Unsaved changes will be lost upon reboot.
- Page 6: System Information
- Displays network and build details: Hostname, SSID, IP Address, and Firmware Version.
- Page 7: System Tools
- Allows selection of three critical functions: AP Mode (force access point mode), Reboot device, and Reset (Factory Reset) device.
- Confirmation: To prevent accidental triggers, these actions require a long-press with a visual incremental timer-bar.

### 2.0.2 Web Interface & Configuration

The device features a responsive Web UI for remote monitoring and full system configuration. Users can connect by a browser directly to device's IP and access to the Web User Interface.
The IP and SSID are visibles on LCD's page 6.
- Home Page (Real-Time Dashboard)
The landing page provides an immediate overview of the device status, electrical parameters and connections status:
- Connectivity Status: Three dynamic badges (AP Mode, Wi-Fi, and MQTT). Status is indicated by color: Grey for inactive/disconnected, Green/Blue for active/connected.
- Live Telemetry: Displays Power (W), Voltage (V), Current (A).
- System Uptime: Tracks operational time in a "Days hh:mm:ss" format.
- Data Refresh: The page features an asynchronous auto-refresh every 10 seconds, with a manual "Refresh" button also available.
- Navigation: Direct links to the Configuration Page and the current Firmware Version footer.
- Configuration Page
This restricted area allows for deep customization of the device behavior and network integration:
- General Settings:
- Hostname: Defines the device identity on the network.
- Manufacturer: Metadata used for network discovery and Home Assistant integration.
- Language: Localization support (currently IT or EN).
- Alarm Threshold (W): Software-defined limit for the acoustic buzzer.
- Buzzer Mode: Selection between Continuous, Slow Intermittent, or Fast Intermittent.
- Wi-Fi Setup:
- Wi-Fi Credentials: SSID and Password configuration.
- IP Assignment: Toggle between DHCP (automatic) or Static IP. If Static is selected, conditional fields appear for IP Address, Subnet Mask, Gateway, and DNS.
- MQTT Setup (Optional):
- Connection parameters including Broker IP, Port, and optional Authentication (Username/Password) for secured environments.
- Buttons:
- Save & Reboot (Red): Commits changes to non-volatile memory and restarts the device.
- Reboot (Red): Performs a standard hardware restart.
- Firmware Update: Redirects to the OTA (Over-The-Air) update interface.
- Home: Returns to the main dashboard.

### Manufacturing & Assembly Notes

### 3.0 Hardware Configuration

- ADS1115 I2C Address Selection: Is hardware-defined through two "0-Ohm bridge" resistors: R16 and R17. These resistors act as jumpers to set the logic level of the ADDR pin (Pin 1) of the ADS1115. Only one of these resistors must be populated at a time:
- R16: Connects the ADDR pin to +3.3V, ADS1115 Address 0x49
- R17: Connects the ADDR pin to GND, ADS1115 Address 0x48 (Default).
- PCF8574 I2C Address Selection: The I2C address of the PCF8574 is determined by the logic levels of pins A0, A1, and A2. With the default configuration where A0 is connected to +3.3V (High) and A1, A2 are connected to GND (Low), the resulting 7-bit I2C address is 0x21. Note: The base address for the PCF8574 family is 0x20. The configuration [A2=L, A1=L, A0=H] corresponds to binary 0100 001, resulting in the hexadecimal address 0x21.
- Safety Design: To prevent assembly errors, the PCB layout utilizes a shared common pad for both R16 and R17. This physical constraint makes it nearly impossible to populate both resistors simultaneously, effectively protecting the +3.3V rail from a direct short circuit to Ground. However, be careful when assembling.

### Assembly Layout: TOP Layer

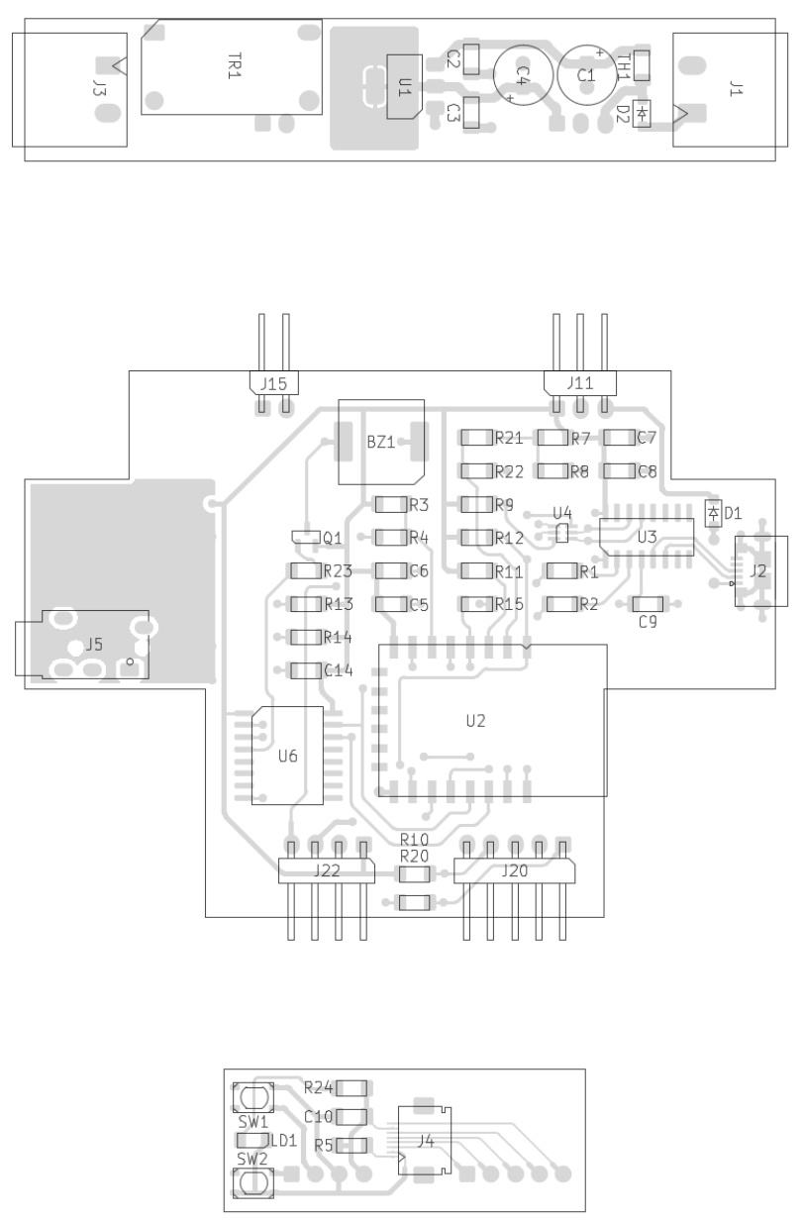
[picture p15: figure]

### Assembly Layout: BOTTOM Layer

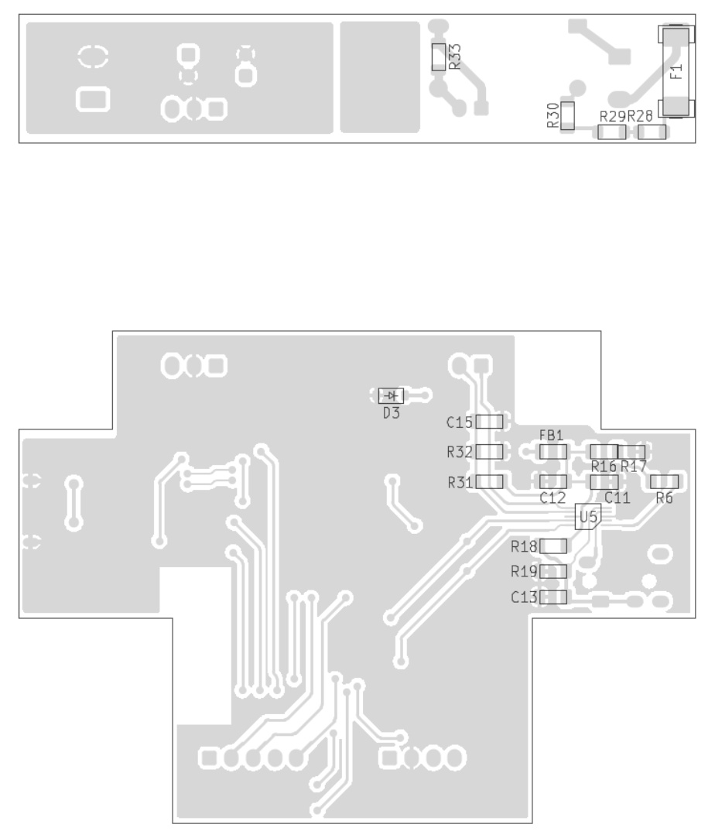
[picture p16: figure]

### Dimensions

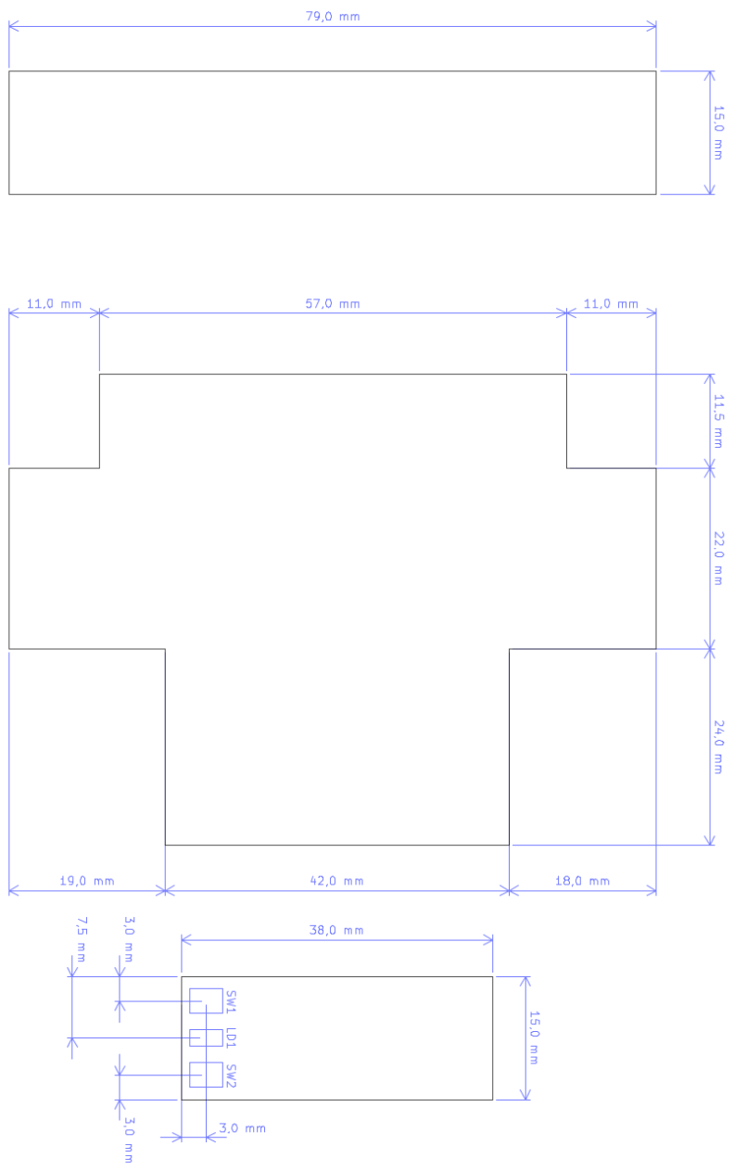
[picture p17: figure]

### Firmware

### 4.0 Firmware

Peter The Power Meter has an embedded firmware designed for real-time single-phase energy monitoring. The system samples AC voltage and current waveforms, calculates Root Mean Square (RMS) values and active power consumption, provides a multi-page visual interface on a TFT display, and integrates with home automation systems via the MQTT protocol.
Technical Specifications
- Language: C++ (Standard C++11/14).
- Framework: Arduino Core for ESP8266.
- Development Environment: PlatformIO.
- Core Hardware: Espressif ESP8266 (e.g., Wemos D1 Mini).
- Data Acquisition: External ADS1115 16-bit ADC connected via I2C for high-precision differential sampling.
- Sensor Support: Current Transformers (SCT-013), Voltage Transformers (ZMPT107-1), and PTC temperature sensors (TFPT1206).
Key Features
- High-Speed Sampling & RMS Calculation: Performs rapid sampling of sinusoidal signals to calculate precise Voltage RMS, Current RMS, and Active Power (W) over a sliding 1-second window.
- Display Management: Features a multi-page User Interface on an ST7735 (0.96" TFT) display. It includes real-time power trend graphs, connectivity status badges, and system information pages.
- IoT & Home Automation:
- MQTT Telemetry: Transmits energy data using a time-weighted average calculated over the publishing interval (default 20s). This optimization minimizes network congestion while maintaining high data accuracy.
- Home Assistant Integration: Fully supports Auto-Discovery, automatically creating sensors and configuration entities (Select/Number) within Home Assistant.
- Embedded Web Server: A built-in web portal protected by HTTP Basic Authentication allows users to configure WiFi credentials, MQTT settings, alarm thresholds, and perform fine sensor calibration (offset and scale).
- Alarm System: Manages a buzzer via a PCF8574 I/O expander with programmable modes (Continuous, Slow Pulse, Fast Pulse) triggered when power exceeds a user-defined threshold.
- Reliability & Maintenance:
- Resilient Connectivity: Implements an exponential backoff strategy for WiFi and MQTT reconnection.
- OTA Updates: Supports Over-The-Air firmware updates through the web interface.
- Localization: Built-in multi-language support (English and Italian) using PROGMEM to optimize RAM usage.

### 4.0.1 Sensor Calibration & Physics Guide (include/config.h)

The following constants define how the raw electrical signals from the sensors are translated into human-readable values (Amps, Volts, Watts).
- Current Conversion (FACTOR_A_V)
Description: This is the scaling factor for the Current Transformer (CT). It converts the voltage measured by the ADC into RMS Amperes. Formula: I_RMS = V_ADC * FACTOR_A_V
Configuration: The FACTOR_A_V of 25.0f is set based on the characteristics of the SCT-013 current transformer. This specific configuration implies that the CT, along with its internal burden resistor, is designed to output 1mA for every 25A flowing through the primary circuit. This 1mA current is then converted into a voltage signal readable by the ADC. Therefore, a 1V RMS signal measured by the ADC corresponds to 25A RMS in the primary circuit.
When to change: This constant must be updated if:
1. You replace the SCT-013 with a model that has a different Current/Voltage ratio (e.g., 30A/1V or 100A/50mA).
2. You add or change an external burden resistor in parallel with the CT output.
- Voltage Conversion (FACTOR_V_V)
Description: This factor scales the low-voltage signal from the ZMPT107-1 transformer back to the actual grid voltage.
Formula: V_Grid = V_ADC * FACTOR_V_V
Configuration: The ZMPT107-1 is a 1:1 voltage transformer. In this setup, the primary side of the ZMPT107-1 is connected to an equivalent resistance of 246KΩ (achieved by three 82KΩ resistors in series). The secondary side uses a 1KΩ burden resistor to convert the current back into a voltage, which is then biased for the ADC input. The FACTOR_V_V of 246.0f is derived directly from the ratio of the primary resistance (246KΩ) to the burden resistance (1KΩ). This means that for every 1V RMS measured at the ADC input, it represents 246V RMS in the grid. When to change: This constant must be updated if you modify the scaling "divider":
1. If you change the series resistors on the Primary side (e.g., to support higher voltages or reduce heat).
2. If you change the burden resistor on the Secondary side (e.g., using a 470Ω or 2kΩ resistor instead of 1kΩ).
Note: Changing the bias resistors (the 10kΩ resistors providing the 1.65V offset) does not affect this factor, as the ADS1115 measures the signal differentially across the burden resistor, effectively ignoring the common-mode DC offset.
- ADC Precision (ADS_GAIN & ADS_MULTIPLIER)
Description: These settings configure the ADS1115 (16-bit ADC) range and resolution.
Technical Detail: GAIN_TWO sets the full-scale range to ±2.048V. Since the ADC is 16-bit signed, the multiplier is calculated as 2.048 / 32768 = 0.0000625.
Important: Do not change these. The hardware is optimized for this range. Increasing the gain will cause the signal to "clip" (saturate) at high power loads, leading to incorrect readings.
- Sampling Rate (ADS_SPS)
Description: Sets the sampling speed to 860 Samples Per Second.
Why it matters: To calculate an accurate RMS value for a 50Hz or 60Hz AC wave, we need to take as many "snapshots" of the wave as possible. 860 SPS is the maximum stable rate for the ADS1115 and provides high fidelity for power calculations.

- Noise and Safety Thresholds
CURRENT_NOISE_FLOOR (0.002f): This is a software filter. If the measured voltage from the CT is below 2mV, the firmware forces the current to 0.0A. This prevents the display from showing small "ghost" consumption caused by background electromagnetic noise. VOLTAGE_MIN_THRESHOLD (50.0f): If the measured voltage is below 50V, the system assumes the voltage sensor is either faulty or disconnected. In this case, it falls back to the DEFAULT_GRID_VOLTAGE (230V) to allow power estimation based on current alone.
- Temperature Monitoring
PTC_AVG_SAMPLES (10): The ESP8266 internal ADC (used for the PTC temperature sensor) can be noisy. We average 10 readings to provide a smooth and stable temperature value.
TEMP_WARNING_THRESHOLD (45.0f): This is a safety limit used for reminder. If the internal temperature of the device exceeds 45°C, the display text turns RED to alert the user of potential overheating.

Summary Table for Quick Reference

Constant | Default Value | Unit | Description
FACTOR_A_V | 25.0 | A/V | Ratio of Amps per Volt from the CT circuit.
FACTOR_V_V | 240.0 | V/V | Ratio of Grid Volts per Volt from the VT circuit.
ADS_GAIN | GAIN_TWO | - | Sets ADC input range to ±2.048V.
ADS_SPS | 860 | Hz | Samples taken per second from the AC wave.
CURRENT_NOISE_FLOOR | 0.002 | V | Minimum voltage to consider a valid current reading.
VOLTAGE_MIN_THRESHOLD | 50.0 | V | Voltage below which the system uses a fallback value.

### 4.0.2 Per-device calibration limits (include/config.h)

These constants define the acceptable range and default values for the calibration parameters that are stored in EEPROM and applied at runtime. These parameters allow for fine-tuning sensor readings to compensate for component tolerances and environmental factors, ensuring maximum accuracy.
- Default Multiplicative Scale (CAL_SCALE_DEFAULT)
Description: This defines the default value for all multiplicative scale factors (voltage, current). A value of 1.0f signifies no correction, meaning the raw sensor reading (after initial hardware scaling) is used directly.
Usage: When the device is first initialized or after a factory reset, calibration scale factors will revert to this default.
- Scale Factor Limits (CAL_SCALE_MIN, CAL_SCALE_MAX)
Description: These constants set the minimum (0.1f) and maximum (10.0f) allowed values for any calibration scale factor (e.g., calScaleV, calScaleA).
Purpose: They prevent users from entering extreme or physically impossible scale values through the web interface, safeguarding the system from erroneous readings or instability.
- Voltage Offset Limits (CAL_OFFSET_V_MIN, CAL_OFFSET_V_MAX) Description: These define the permissible range for the voltage offset calibration parameter (calOffsetV). The offset is applied after the scaling factor.

Range: From -500.0f to 500.0f Volts.
Purpose: This allows for small additive corrections to the measured voltage, compensating for minor discrepancies in the voltage sensing circuit that are not linear across the entire measurement range.
- Current Offset Limits (CAL_OFFSET_A_MIN, CAL_OFFSET_A_MAX) Description: These define the permissible range for the current offset calibration parameter (calOffsetA). The offset is applied after the scaling factor.
Range: From -100.0f to 100.0f Amperes.
Purpose: Similar to voltage offset, this corrects for any baseline inaccuracies in current readings, particularly important at very low current levels to ensure a true zero reading when no current is flowing.
- Temperature Offset Limits (CAL_OFFSET_TEMP_MIN, CAL_OFFSET_TEMP_MAX) Description: These define the permissible range for the temperature offset calibration parameter (calOffsetTemp).
Range: From -50.0f to 50.0f degrees Celsius.
Purpose: This allows for adjusting the reported temperature to match a known reference, accounting for variations in the PTC sensor or its placement.

Summary Table: Per-Device Calibration Limits

Constant | Default/ Range | Unit | Description
CAL_SCALE_DEFAULT | 1.0f | - | Default multiplicative scale factor (no correction).
CAL_SCALE_MIN | 0.1f | - | Minimum allowed value for scale factors.
CAL_SCALE_MAX | 10.0f | - | Maximum allowed value for scale factors.
CAL_OFFSET_V_MIN | -500.0f | V | Minimum allowed voltage offset.
CAL_OFFSET_V_MAX | 500.0f | V | Maximum allowed voltage offset.
CAL_OFFSET_A_MIN | -100.0f | A | Minimum allowed current offset.
CAL_OFFSET_A_MAX | 100.0f | A | Maximum allowed current offset.
CAL_OFFSET_TEMP_MIN | -50.0f | °C | Minimum allowed temperature offset.
CAL_OFFSET_TEMP_MAX | 50.0f | °C | Maximum allowed temperature offset.

### 4.0.3 PTC Calibration & Hardware (include/config.h)

The device monitors its internal temperature using a PTC (Positive Temperature Coefficient) sensor (specifically the TFPT1206 series). The sensor is part of a voltage divider circuit connected to the ESP8266's analog input (A0). The firmware performs a multi-stage calculation to reconstruct the actual resistance of the sensor and convert it into a precise temperature reading.
- Voltage Source & Reference (PTC_V_SOURCE)
Description: This is the regulated DC supply voltage used to power the temperature sensing divider.
Value: 3.3f (Standard logic voltage for the ESP8266).
When to change: Only if the sensing circuit is powered by a different voltage rail (e.g., 5V, though not recommended for this hardware).
- Divider Pull-Up Resistor (PTC_R_PULLUP)
Description: The fixed resistor R7 that forms the upper branch of the voltage divider with the PTC sensor.
Usage: It determines the voltage-to-resistance curve. A value of 33kΩ provides a good balance of sensitivity and range for the 10kΩ PTC sensor.

When to change: If you physically replace the R7 resistor on the PCB with a different value.
- ADC Input Stage Compensation (PTC_R_DIVIDER_TOTAL & PTC_R_DIVIDER_LOAD) Description: These constants compensate for the voltage divider typically found on ESP8266 modules (like the Wemos D1 Mini) that maps a 0-3.3V input to the 0-1V range required by the internal ADC chip. Technical Detail:
PTC_R_DIVIDER_TOTAL: The sum of the series resistor R21 and the load resistor R22.
PTC_R_DIVIDER_LOAD: The value of the load resistor R22 connected to GND.
When to change: Only if you are using a bare ESP-12F chip without an external divider on the ADC pin, or if your specific module uses different values (e.g., standard Wemos modules often use 220k/100k, resulting in a total of 320k).
- Sensor Characteristics (PTC_NOMINAL_RES & PTC_COEFF) PTC_NOMINAL_RES (10,000):
The base resistance of the PTC sensor in Ohms at the reference temperature of 25°C.
PTC_COEFF (0.00411): The Temperature Coefficient of Resistance (TCR). It defines the linear slope of the resistance change per degree Celsius.
Formula: The temperature is derived using a linear approximation around 25°C: Temperature = {[(R_PTC / PTC_NOMINAL_RES) - 1] / PTC_COEFF} + 25 + Offset
When to change: If you use a different model of PTC sensor (e.g., a 1kΩ or 5kΩ version) or a sensor with a different TCR slope.

Summary Table: Temperature Sensing Constants
Constant | Default Value | Unit | Description
PTC_V_SOURCE | 3.3 | V | Logic source voltage for the sensing branch.
PTC_R_PULLUP | 33,000 | Ω | Fixed pull-up resistor ($R_7$) in the divider.
PTC_NOMINAL_RES | 10,000 | Ω | PTC resistance at 25°C.
PTC_COEFF | 0.00411 | - | TCR (Temperature Coefficient) of the sensor.
PTC_R_DIVIDER_TOTAL | 100,220 | Ω | ADC input stage total resistance ($R_{21} + R_{22}$).

### License

This project is licensed under the MIT License.
Note on Attribution: While the MIT license allows for free use and modification, I kindly request that any clones, forks, or derivative works (both hardware and software) maintain a clear attribution to the original author and a link back to this repository.

MIT License

Copyright (c) 2026 CtrlAltJon

Permission is hereby granted, free of charge, to any person obtaining a copy of this software and associated documentation files (the "Software"), to deal in the Software without restriction, including without limitation the rights to use, copy, modify, merge, publish, distribute, sublicense, and/or sell copies of the Software, and to permit persons to whom the Software is furnished to do so, subject to the following conditions:

The above copyright notice and this permission notice shall be included in all
copies or substantial portions of the Software.

THE SOFTWARE IS PROVIDED "AS IS", WITHOUT WARRANTY OF ANY KIND, EXPRESS OR IMPLIED, INCLUDING BUT NOT LIMITED TO THE WARRANTIES OF MERCHANTABILITY, FITNESS FOR A PARTICULAR PURPOSE AND NONINFRINGEMENT. IN NO EVENT SHALL THE AUTHORS OR COPYRIGHT HOLDERS BE LIABLE FOR ANY CLAIM, DAMAGES OR OTHER LIABILITY, WHETHER IN AN ACTION OF CONTRACT, TORT OR OTHERWISE, ARISING FROM, OUT OF OR IN CONNECTION WITH THE SOFTWARE OR THE USE OR OTHER DEALINGS IN THE SOFTWARE.

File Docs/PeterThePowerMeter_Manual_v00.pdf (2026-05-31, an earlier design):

# POWER METER

with ESP8266 and ADS1115

Last update, 30/05/2026

### Disclaimer

### ⚠️ IMPORTANT SAFETY WARNING & DISCLAIMER

THIS PROJECT INVOLVES WORKING WITH HIGH VOLTAGE (230VAC). HIGH VOLTAGE CAN CAUSE SEVERE INJURY, ELECTROCUTION, OR DEATH. FIRE HAZARD IS ALSO PRESENT.

This project is provided "as is", for educational and hobbyist purposes only. By using any part of this project (including hardware designs, PCB layouts, and software), you acknowledge and agree to the following:
1.Assumption of Risk: You are solely responsible for your own safety and for any damage caused by the assembly, testing, or use of this device. 2.No Liability: The author(s) shall not be held liable for any direct or indirect damages, including but not limited to: hardware failure, data loss, property damage (fire, short circuits), personal injury, or death, resulting from the use or misuse of this project.
3.Assembly & Modification: Any errors in assembly, soldering (e.g., solder bridges), component selection, firmware modification or others actions are the sole responsibility of the user.
4.No Warranty: There is no guarantee regarding the accuracy of measurements, the stability of the software, or the safety of the hardware design for long-term use.
5.Local Standards: It is the user's responsibility to ensure that the device complies with local electrical codes and safety regulations. IF YOU ARE NOT EXPERIENCED IN WORKING WITH MAINS VOLTAGE, DO NOT ATTEMPT TO BUILD THIS PROJECT.

### Revision History

- 00: First release (30/05/2026)

### Design Rationale & Project Overview

### 1.1 System Architecture

This project is a Digital Power Meter designed for real-time energy monitoring with acoustic alarm when a threshold is exceeded. The system is engineered to fit within a standard 1-module DIN rail enclosure (roughly the size of a standard miniature circuit breaker), making it ideal for integration into domestic electrical panels.

At the moment, the 3D design/CAD file for the DIN enclosure is not available. Contributions regarding the design of a suitable enclosure are highly welcome and would be a valuable addition to this project.

The system architecture is based on the ESP8266 (ESP-12F) microcontroller, leveraging its Wi-Fi capabilities for IoT integration and an ADS1115 to read voltage and current. For system health, an onboard TFPT1206L1002DV temperature sensor is included to monitor the internal thermal conditions of the enclosure.
For local interaction, the device features a 0.96" color LCD display that provides real-time data visualization and configuration menus. Users can navigate through multiple data pages and perform basic setup tasks using a multi-function physical button. Additionally, the system hosts a built-in Web Server, allowing for advanced remote configuration, firmware updates (OTA), and detailed system management via an intuitive Web UI.
The measurement stage utilizes two primary sensors:
- Voltage Sensing: Handled via a dedicated voltage transformer ZMPT107-1 (TR1) for galvanic isolation and safety.
- Current Sensing: Implemented using the SCT-013 split-core current transformer (clamp meter).
Both sensors provide a 1VAC sinusoidal output. These signals are conditioned via a voltage divider network and sampled by an ADS1115 16-bit ADC, which communicates with the MCU via the I2C protocol.

### 1.2 Hardware Features & User Interface

To optimize GPIO usage, a PCF8574 I/O expander is employed for digital signal management and future use. The user interface consists of:
- Buttons: A multi-function navigation button (Short press: Page toggle | Long press: Confirm/Action) and a dedicated Pin-hole Hardware Reset
button connected directly to Pin 1 (RST) of the ESP8266.
- Acoustic Feedback: An active piezoelectric buzzer triggers an audible alarm when a software-defined power threshold is exceeded.

- Thermal Monitoring: An onboard TFPT1206L1002DV temperature sensor (PTC thermistor) is integrated into the circuit. This component allows the system to monitor the internal temperature of the enclosure.
- Display: A 0.96" Color LCD for local monitoring and basic interaction.
- Web Server: A Web User Interface for remote monitoring and full system configuration.

### 1.3 Power Supply & Protection

The device supports 2 power input options and 1 input 230VAC for Voltage reading:
1.Terminal Block (J1): Accepts a +5VDC regulated supply.
- Warning - No reverse polarity protection:
This input currently lacks reverse polarity protection; correct orientation is mandatory.

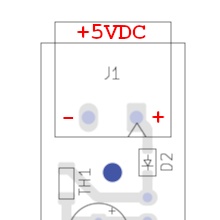
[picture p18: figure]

2.USB Connector (J2): For secondary power or debugging.
- Communication & Debugging: This interface utilizes a CH340C USB-to-Serial bridge and a UMH3NFHATN transistor pair to communicate with the ESP8266. This setup enables full debugging, serial communication, and firmware programming (automatic reset/bootloader entry).
- Safety Feature: The board implements a dual Schottky diode protection circuit on the positive rails of both J1 and J2. This prevents back-feeding, though it is recommended to disconnect J1 when using USB power.
- Overcurrent Protection: The +5VDC main rail is protected by a MF-NSMF050-2 PTC (Resettable Fuse) rated at 500mA.
3.AC Voltage Input (J3): High-voltage input for the ZMPT107-1 transformer.
- Polarity Recommendation: Although the transformer operates on AC, it is strictly recommended to respect the Phase (L) and Neutral
(N) markings.

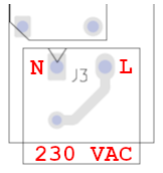
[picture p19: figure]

- Safety Rationale: The protection fuse is located exclusively on the Phase line. Inverting the polarity would mean that, in the event of a fault or a blown fuse, the Neutral line would be disconnected while the entire internal circuit remains energized (live) through the Phase line. This creates a severe electrocution hazard even when the device appears to be non-functional.
- Safety Design: The circuit features a 250mA T (Slow-blow) fuse placed exclusively on the Phase line. Additionally, the line is equipped with three resistors in series designed to limit the current to 1mA RMS at 230V, providing an essential layer of protection for the sensing stage.

### 1.4 Operational Limits & Grid Compatibility

This device is specifically designed and calibrated for 230VAC/50Hz Phase-Neutral grids (Standard European Grid).
- Voltage Specificity: The internal components, including the protection resistors and the ZMPT107-1 transformer ratio, are optimized for 230V. Use with different mains voltages (e.g., 110-120V) may result in inaccurate readings or insufficient signal-to-noise ratio.
- Frequency Specificity: The system is tuned for 50Hz operation. While the magnetic components (TR1 and CT) can physically handle 60Hz, the firmware's sampling window and RMS calculation algorithms are optimized for a 20ms period.
- Warning: Operation on different grid standards, high-voltage industrial lines, or Phase-to-Phase configurations (without a neutral line) may exceed the safety ratings of the components and the fuse, leading to hardware failure or fire hazard.

### 2.0 Connectivity & Software Integration

The firmware architecture features a built-in Web Server for real-time monitoring, local configuration, and connections management (Wi-Fi and MQTT). The device natively supports the MQTT protocol for a smart home integration with platforms such as Home Assistant.

### 2.0.1 LCD User Interface (Vertical Orientation)

The 0.96" display provides a multi-page interface for local data visualization and system control. Navigation is handled via the multi-
function button (Short press: Page toggle | Long press: Confirm/Action).
- Page 1: Real-time Monitor
- Power: Current power consumption displayed in kW.
- Temperature: PCB temperature in °C.
- Graph: A rolling history graph showing power trends (approx. 1-minute window).
- Status Badges: Dynamic icons for Wi-Fi connection status (Green:
Connected | Blue: Access Point Mode) and MQTT connection status
(Green: Connected to server | Grey: Disconnected from server).
- Page 2: Power Threshold Configuration
- Displays the active alarm threshold (Watts).

- Allows cyclic adjustment of the new threshold (100W increments) via long-press. The value wraps around to zero once the upper limit is reached.
- Page 3: Voltage Monitoring
- Displays the real-time mains voltage (V) as measured by the ZMPT107-1 transformer.
- Page 4: Acoustic Alarm Settings
- Displays the current buzzer mode: Continuous, Slow Intermittent, or Fast Intermittent.
- Users can cycle through these modes via long-press.
- Page 5: Save Settings
- Summarizes the current threshold and buzzer configurations.
- Action: A long-press commits these settings to non-volatile memory. Note: Unsaved changes will be lost upon reboot.
- Page 6: System Information
- Displays network and build details: Hostname, SSID, IP Address, and Firmware Version.
- Page 7: System Tools
- Allows selection of three critical functions: AP Mode (force access point mode), Reboot device, and Reset (Factory Reset) device.
- Confirmation: To prevent accidental triggers, these actions require a long-press with a visual incremental timer-bar.

### 2.0.2 Web Interface & Configuration

The device features a responsive Web UI for remote monitoring and full system configuration. Users can connect by a browser directly to device's IP and access to the Web User Interface.
The IP and SSID are visibles on LCD's page 6.
- Home Page (Real-Time Dashboard)
The landing page provides an immediate overview of the device status, electrical parameters and connections status:
- Connectivity Status: Three dynamic badges (AP Mode, Wi-Fi, and MQTT). Status is indicated by color: Grey for inactive/disconnected, Green/Blue for active/connected.
- Live Telemetry: Displays Power (W), Voltage (V), Current (A).
- System Uptime: Tracks operational time in a "Days hh:mm:ss" format.
- Data Refresh: The page features an asynchronous auto-refresh every 10 seconds, with a manual "Refresh" button also available.
- Navigation: Direct links to the Configuration Page and the current Firmware Version footer.
- Configuration Page
This restricted area allows for deep customization of the device behavior and network integration:
- General Settings:
- Hostname: Defines the device identity on the network.

- Manufacturer: Metadata used for network discovery and Home Assistant integration.
- Language: Localization support (currently IT or EN).
- Alarm Threshold (W): Software-defined limit for the acoustic buzzer.
- Buzzer Mode: Selection between Continuous, Slow Intermittent, or Fast Intermittent.
- Wi-Fi Setup:
- Wi-Fi Credentials: SSID and Password configuration.
- IP Assignment: Toggle between DHCP (automatic) or Static IP. If Static is selected, conditional fields appear for IP Address, Subnet Mask, Gateway, and DNS.
- MQTT Setup (Optional):
- Connection parameters including Broker IP, Port, and optional Authentication (Username/Password) for secured environments.
- Buttons:
- Save & Reboot (Red): Commits changes to non-volatile memory and restarts the device.
- Reboot (Red): Performs a standard hardware restart.
- Firmware Update: Redirects to the OTA (Over-The-Air) update interface.
- Home: Returns to the main dashboard.

### Manufacturing & Assembly Notes

### 3.0 Hardware Configuration

- ADS1115 I2C Address Selection: Is hardware-defined through two "0-Ohm bridge" resistors: R16 and R17. These resistors act as jumpers to set the logic level of the ADDR pin (Pin 1) of the ADS1115. Only one of these resistors must be populated at a time:
- R16: Connects the ADDR pin to +3.3V, ADS1115 Address 0x49
- R17: Connects the ADDR pin to GND, ADS1115 Address 0x48 (Default).
- PCF8574 I2C Address Selection: The I2C address of the PCF8574 is determined by the logic levels of pins A0, A1, and A2. With the default configuration where A0 is connected to +3.3V (High) and A1, A2 are connected to GND (Low), the resulting 7-bit I2C address is 0x21. Note: The base address for the PCF8574 family is 0x20. The configuration [A2=L, A1=L, A0=H] corresponds to binary 0100 001, resulting in the hexadecimal address 0x21.
- Safety Design: To prevent assembly errors, the PCB layout utilizes a shared common pad for both R16 and R17. This physical constraint makes it nearly impossible to populate both resistors simultaneously, effectively protecting the +3.3V rail from a direct short circuit to Ground. However, be careful when assembling.

### Assembly Layout: TOP Layer

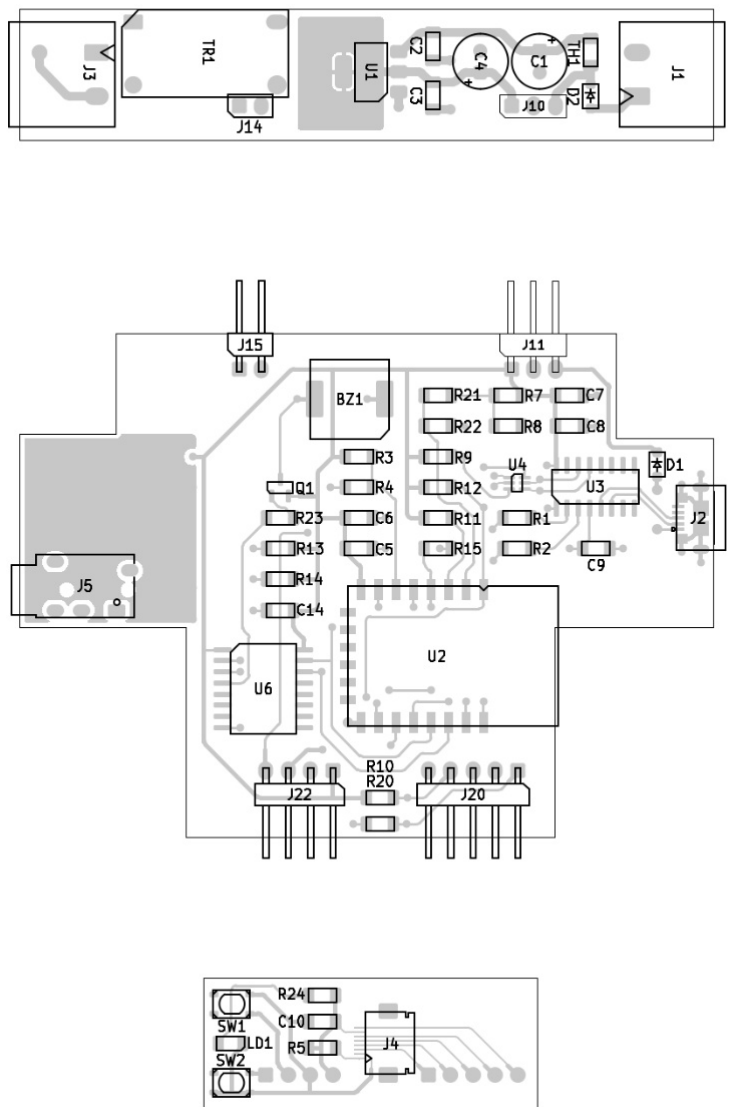
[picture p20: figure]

### Assembly Layout: BOTTOM Layer

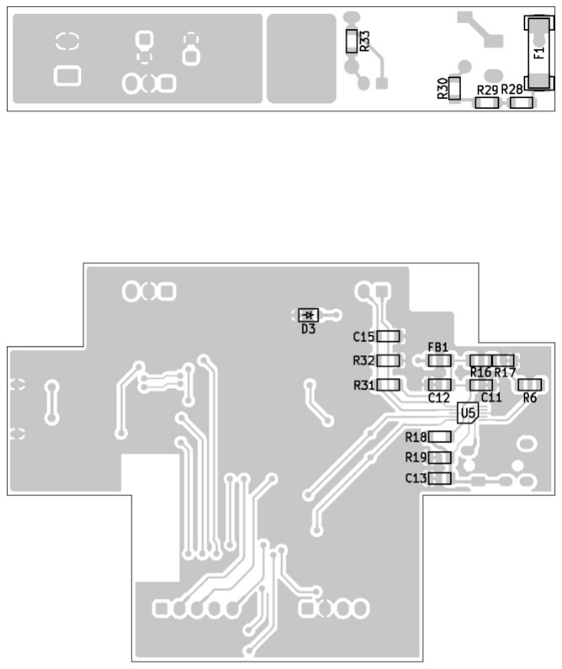
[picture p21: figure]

### Dimensions

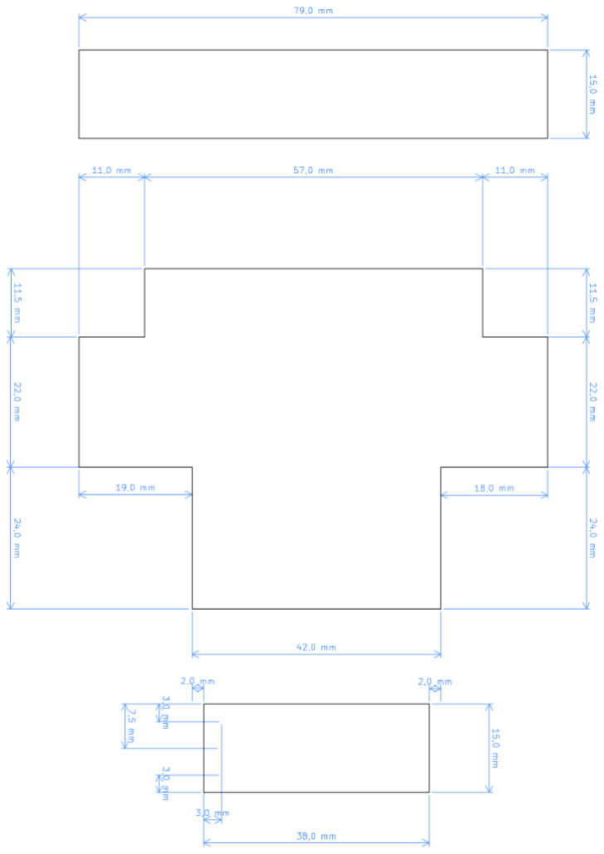
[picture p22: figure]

### Firmware

### 4.0 Firmware

Peter The Power Meter has an embedded firmware designed for real-time single-phase energy monitoring. The system samples AC voltage and current waveforms, calculates Root Mean Square (RMS) values and active power consumption, provides a multi-page visual interface on a TFT display, and integrates with home automation systems via the MQTT protocol.
Technical Specifications
- Language: C++ (Standard C++11/14).
- Framework: Arduino Core for ESP8266.
- Development Environment: PlatformIO.
- Core Hardware: Espressif ESP8266 (e.g., Wemos D1 Mini).
- Data Acquisition: External ADS1115 16-bit ADC connected via I2C for high-precision differential sampling.
- Sensor Support: Current Transformers (SCT-013), Voltage Transformers (ZMPT107-1), and PTC temperature sensors (TFPT1206).
Key Features
- High-Speed Sampling & RMS Calculation: Performs rapid sampling of sinusoidal signals to calculate precise Voltage RMS, Current RMS, and Active Power (W) over a sliding 1-second window.
- Display Management: Features a multi-page User Interface on an ST7735 (0.96" TFT) display. It includes real-time power trend graphs, connectivity status badges, and system information pages.
- IoT & Home Automation:
- MQTT Telemetry: Transmits energy data using a time-weighted average calculated over the publishing interval (default 20s). This optimization minimizes network congestion while maintaining high data accuracy.
- Home Assistant Integration: Fully supports Auto-Discovery, automatically creating sensors and configuration entities (Select/Number) within Home Assistant.
- Embedded Web Server: A built-in web portal protected by HTTP Basic Authentication allows users to configure WiFi credentials, MQTT settings, alarm thresholds, and perform fine sensor calibration (offset and scale).
- Alarm System: Manages a buzzer via a PCF8574 I/O expander with programmable modes (Continuous, Slow Pulse, Fast Pulse) triggered when power exceeds a user-defined threshold.
- Reliability & Maintenance:
- Resilient Connectivity: Implements an exponential backoff strategy for WiFi and MQTT reconnection.

- OTA Updates: Supports Over-The-Air firmware updates through the web interface.
- Localization: Built-in multi-language support (English and Italian) using PROGMEM to optimize RAM usage.

### 4.0.1 Sensor Calibration & Physics Guide (include/config.h)

The following constants define how the raw electrical signals from the sensors are translated into human-readable values (Amps, Volts, Watts).
- Current Conversion (FACTOR_A_V)
Description: This is the scaling factor for the Current Transformer (CT). It converts the voltage measured by the ADC into RMS Amperes. Formula: I_RMS = V_ADC * FACTOR_A_V
Configuration: The FACTOR_A_V of 25.0f is set based on the characteristics of the SCT-013 current transformer. This specific configuration implies that the CT, along with its internal burden resistor, is designed to output 1mA for every 25A flowing through the primary circuit. This 1mA current is then converted into a voltage signal readable by the ADC. Therefore, a 1V RMS signal measured by the ADC corresponds to 25A RMS in the primary circuit.
When to change: This constant must be updated if:
1. You replace the SCT-013 with a model that has a different Current/Voltage ratio (e.g., 30A/1V or 100A/50mA).
2. You add or change an external burden resistor in parallel with the CT output.
- Voltage Conversion (FACTOR_V_V)
Description: This factor scales the low-voltage signal from the ZMPT107-1 transformer back to the actual grid voltage.
Formula: V_Grid = V_ADC * FACTOR_V_V
Configuration: The ZMPT107-1 is a 1:1 voltage transformer. In this setup, the primary side of the ZMPT107-1 is connected to an equivalent resistance of 246KΩ (achieved by three 82KΩ resistors in series). The secondary side uses a 1KΩ burden resistor to convert the current back into a voltage, which is then biased for the ADC input. The FACTOR_V_V of 246.0f is derived directly from the ratio of the primary resistance (246KΩ) to the burden resistance (1KΩ). This means that for every 1V RMS measured at the ADC input, it represents 246V RMS in the grid. When to change: This constant must be updated if you modify the scaling "divider":
1. If you change the series resistors on the Primary side (e.g., to support higher voltages or reduce heat).
2. If you change the burden resistor on the Secondary side (e.g., using a 470Ω or 2kΩ resistor instead of 1kΩ).
Note: Changing the bias resistors (the 10kΩ resistors providing the 1.65V offset) does not affect this factor, as the ADS1115 measures the signal differentially across the burden resistor, effectively ignoring the common-mode DC offset.
- ADC Precision (ADS_GAIN & ADS_MULTIPLIER)
Description: These settings configure the ADS1115 (16-bit ADC) range and resolution.
Technical Detail: GAIN_TWO sets the full-scale range to ±2.048V. Since the ADC is 16-bit signed, the multiplier is calculated as 2.048 / 32768 = 0.0000625.
Important: Do not change these. The hardware is optimized for this range. Increasing the gain will cause the signal to "clip" (saturate) at high power loads, leading to incorrect readings.
- Sampling Rate (ADS_SPS)
Description: Sets the sampling speed to 860 Samples Per Second.

Why it matters: To calculate an accurate RMS value for a 50Hz or 60Hz AC wave, we need to take as many "snapshots" of the wave as possible. 860 SPS is the maximum stable rate for the ADS1115 and provides high fidelity for power calculations.
- Noise and Safety Thresholds
CURRENT_NOISE_FLOOR (0.002f): This is a software filter. If the measured voltage from the CT is below 2mV, the firmware forces the current to 0.0A. This prevents the display from showing small "ghost" consumption caused by background electromagnetic noise. VOLTAGE_MIN_THRESHOLD (50.0f): If the measured voltage is below 50V, the system assumes the voltage sensor is either faulty or disconnected. In this case, it falls back to the DEFAULT_GRID_VOLTAGE (230V) to allow power estimation based on current alone.
- Temperature Monitoring
PTC_AVG_SAMPLES (10): The ESP8266 internal ADC (used for the PTC temperature sensor) can be noisy. We average 10 readings to provide a smooth and stable temperature value.
TEMP_WARNING_THRESHOLD (45.0f): This is a safety limit used for reminder. If the internal temperature of the device exceeds 45°C, the display text turns RED to alert the user of potential overheating.

Summary Table for Quick Reference

Constant | Default Value | Unit | Description
FACTOR_A_V | 25.0 | A/V | Ratio of Amps per Volt from the CT circuit.
FACTOR_V_V | 240.0 | V/V | Ratio of Grid Volts per Volt from the VT circuit.
ADS_GAIN | GAIN_TWO | - | Sets ADC input range to ±2.048V.
ADS_SPS | 860 | Hz | Samples taken per second from the AC wave.
CURRENT_NOISE_FLOOR | 0.002 | V | Minimum voltage to consider a valid current reading.
VOLTAGE_MIN_THRESHOLD | 50.0 | V | Voltage below which the system uses a fallback value.

### 4.0.2 Per-device calibration limits (include/config.h)

These constants define the acceptable range and default values for the calibration parameters that are stored in EEPROM and applied at runtime. These parameters allow for fine-tuning sensor readings to compensate for component tolerances and environmental factors, ensuring maximum accuracy.
- Default Multiplicative Scale (CAL_SCALE_DEFAULT)
Description: This defines the default value for all multiplicative scale factors (voltage, current). A value of 1.0f signifies no correction, meaning the raw sensor reading (after initial hardware scaling) is used directly.
Usage: When the device is first initialized or after a factory reset, calibration scale factors will revert to this default.
- Scale Factor Limits (CAL_SCALE_MIN, CAL_SCALE_MAX)
Description: These constants set the minimum (0.1f) and maximum (10.0f) allowed values for any calibration scale factor (e.g., calScaleV, calScaleA).
Purpose: They prevent users from entering extreme or physically impossible scale values through the web interface, safeguarding the system from erroneous readings or instability.

- Voltage Offset Limits (CAL_OFFSET_V_MIN, CAL_OFFSET_V_MAX) Description: These define the permissible range for the voltage offset calibration parameter (calOffsetV). The offset is applied after the scaling factor.
Range: From -500.0f to 500.0f Volts.
Purpose: This allows for small additive corrections to the measured voltage, compensating for minor discrepancies in the voltage sensing circuit that are not linear across the entire measurement range.
- Current Offset Limits (CAL_OFFSET_A_MIN, CAL_OFFSET_A_MAX) Description: These define the permissible range for the current offset calibration parameter (calOffsetA). The offset is applied after the scaling factor.
Range: From -100.0f to 100.0f Amperes.
Purpose: Similar to voltage offset, this corrects for any baseline inaccuracies in current readings, particularly important at very low current levels to ensure a true zero reading when no current is flowing.
- Temperature Offset Limits (CAL_OFFSET_TEMP_MIN, CAL_OFFSET_TEMP_MAX) Description: These define the permissible range for the temperature offset calibration parameter (calOffsetTemp).
Range: From -50.0f to 50.0f degrees Celsius.
Purpose: This allows for adjusting the reported temperature to match a known reference, accounting for variations in the PTC sensor or its placement.

Summary Table: Per-Device Calibration Limits

Constant | Default/ Range | Unit | Description
CAL_SCALE_DEFAULT | 1.0f | - | Default multiplicative scale factor (no correction).
CAL_SCALE_MIN | 0.1f | - | Minimum allowed value for scale factors.
CAL_SCALE_MAX | 10.0f | - | Maximum allowed value for scale factors.
CAL_OFFSET_V_MIN | -500.0f | V | Minimum allowed voltage offset.
CAL_OFFSET_V_MAX | 500.0f | V | Maximum allowed voltage offset.
CAL_OFFSET_A_MIN | -100.0f | A | Minimum allowed current offset.
CAL_OFFSET_A_MAX | 100.0f | A | Maximum allowed current offset.
CAL_OFFSET_TEMP_MIN | -50.0f | °C | Minimum allowed temperature offset.
CAL_OFFSET_TEMP_MAX | 50.0f | °C | Maximum allowed temperature offset.

### 4.0.3 PTC Calibration & Hardware (include/config.h)

The device monitors its internal temperature using a PTC (Positive Temperature Coefficient) sensor (specifically the TFPT1206 series). The sensor is part of a voltage divider circuit connected to the ESP8266's analog input (A0). The firmware performs a multi-stage calculation to reconstruct the actual resistance of the sensor and convert it into a precise temperature reading.
- Voltage Source & Reference (PTC_V_SOURCE)
Description: This is the regulated DC supply voltage used to power the temperature sensing divider.
Value: 3.3f (Standard logic voltage for the ESP8266).
When to change: Only if the sensing circuit is powered by a different voltage rail (e.g., 5V, though not recommended for this hardware).
- Divider Pull-Up Resistor (PTC_R_PULLUP)
Description: The fixed resistor R7 that forms the upper branch of the voltage divider with the PTC sensor.
Usage: It determines the voltage-to-resistance curve. A value of 33kΩ provides a good balance of sensitivity and range for the 10kΩ PTC sensor.
When to change: If you physically replace the R7 resistor on the PCB with a different value.
- ADC Input Stage Compensation (PTC_R_DIVIDER_TOTAL & PTC_R_DIVIDER_LOAD) Description: These constants compensate for the voltage divider typically found on ESP8266 modules (like the Wemos D1 Mini) that maps a 0-3.3V input to the 0-1V range required by the internal ADC chip. Technical Detail:
PTC_R_DIVIDER_TOTAL: The sum of the series resistor R21 and the load resistor R22.
PTC_R_DIVIDER_LOAD: The value of the load resistor R22 connected to GND.
When to change: Only if you are using a bare ESP-12F chip without an external divider on the ADC pin, or if your specific module uses different values (e.g., standard Wemos modules often use 220k/100k, resulting in a total of 320k).
- Sensor Characteristics (PTC_NOMINAL_RES & PTC_COEFF) PTC_NOMINAL_RES (10,000):
The base resistance of the PTC sensor in Ohms at the reference temperature of 25°C.
PTC_COEFF (0.00411): The Temperature Coefficient of Resistance (TCR). It defines the linear slope of the resistance change per degree Celsius.
Formula: The temperature is derived using a linear approximation around 25°C: Temperature = {[(R_PTC / PTC_NOMINAL_RES) - 1] / PTC_COEFF} + 25 + Offset
When to change: If you use a different model of PTC sensor (e.g., a 1kΩ or 5kΩ version) or a sensor with a different TCR slope.

Summary Table: Temperature Sensing Constants
Constant | Default Value | Unit | Description
PTC_V_SOURCE | 3.3 | V | Logic source voltage for the sensing branch.
PTC_R_PULLUP | 33,000 | Ω | Fixed pull-up resistor ($R_7$) in the divider.
PTC_NOMINAL_RES | 10,000 | Ω | PTC resistance at 25°C.
PTC_COEFF | 0.00411 | - | TCR (Temperature Coefficient) of the sensor.
PTC_R_DIVIDER_TOTAL | 100,220 | Ω | ADC input stage total resistance ($R_{21} + R_{22}$).

### License

This project is licensed under the MIT License.
Note on Attribution: While the MIT license allows for free use and modification, I kindly request that any clones, forks, or derivative works (both hardware and software) maintain a clear attribution to the original author and a link back to this repository.

MIT License

Copyright (c) 2026 CtrlAltJon

Permission is hereby granted, free of charge, to any person obtaining a copy of this software and associated documentation files (the "Software"), to deal in the Software without restriction, including without limitation the rights to use, copy, modify, merge, publish, distribute, sublicense, and/or sell copies of the Software, and to permit persons to whom the Software is furnished to do so, subject to the following conditions:

The above copyright notice and this permission notice shall be included in all
copies or substantial portions of the Software.

THE SOFTWARE IS PROVIDED "AS IS", WITHOUT WARRANTY OF ANY KIND, EXPRESS OR IMPLIED, INCLUDING BUT NOT LIMITED TO THE WARRANTIES OF MERCHANTABILITY, FITNESS FOR A PARTICULAR PURPOSE AND NONINFRINGEMENT. IN NO EVENT SHALL THE AUTHORS OR COPYRIGHT HOLDERS BE LIABLE FOR ANY CLAIM, DAMAGES OR OTHER LIABILITY, WHETHER IN AN ACTION OF CONTRACT, TORT OR OTHERWISE, ARISING FROM, OUT OF OR IN CONNECTION WITH THE SOFTWARE OR THE USE OR OTHER DEALINGS IN THE SOFTWARE.

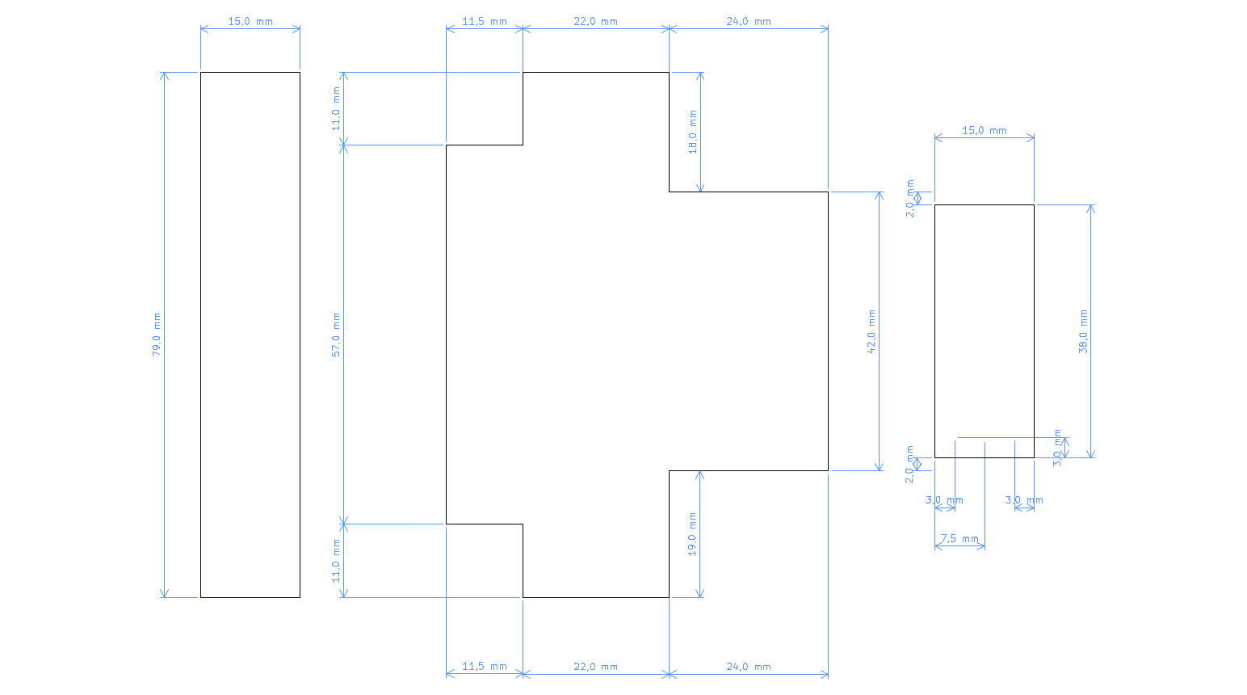
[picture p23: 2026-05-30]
Images/guide-docs/Guide_Dimensions.png

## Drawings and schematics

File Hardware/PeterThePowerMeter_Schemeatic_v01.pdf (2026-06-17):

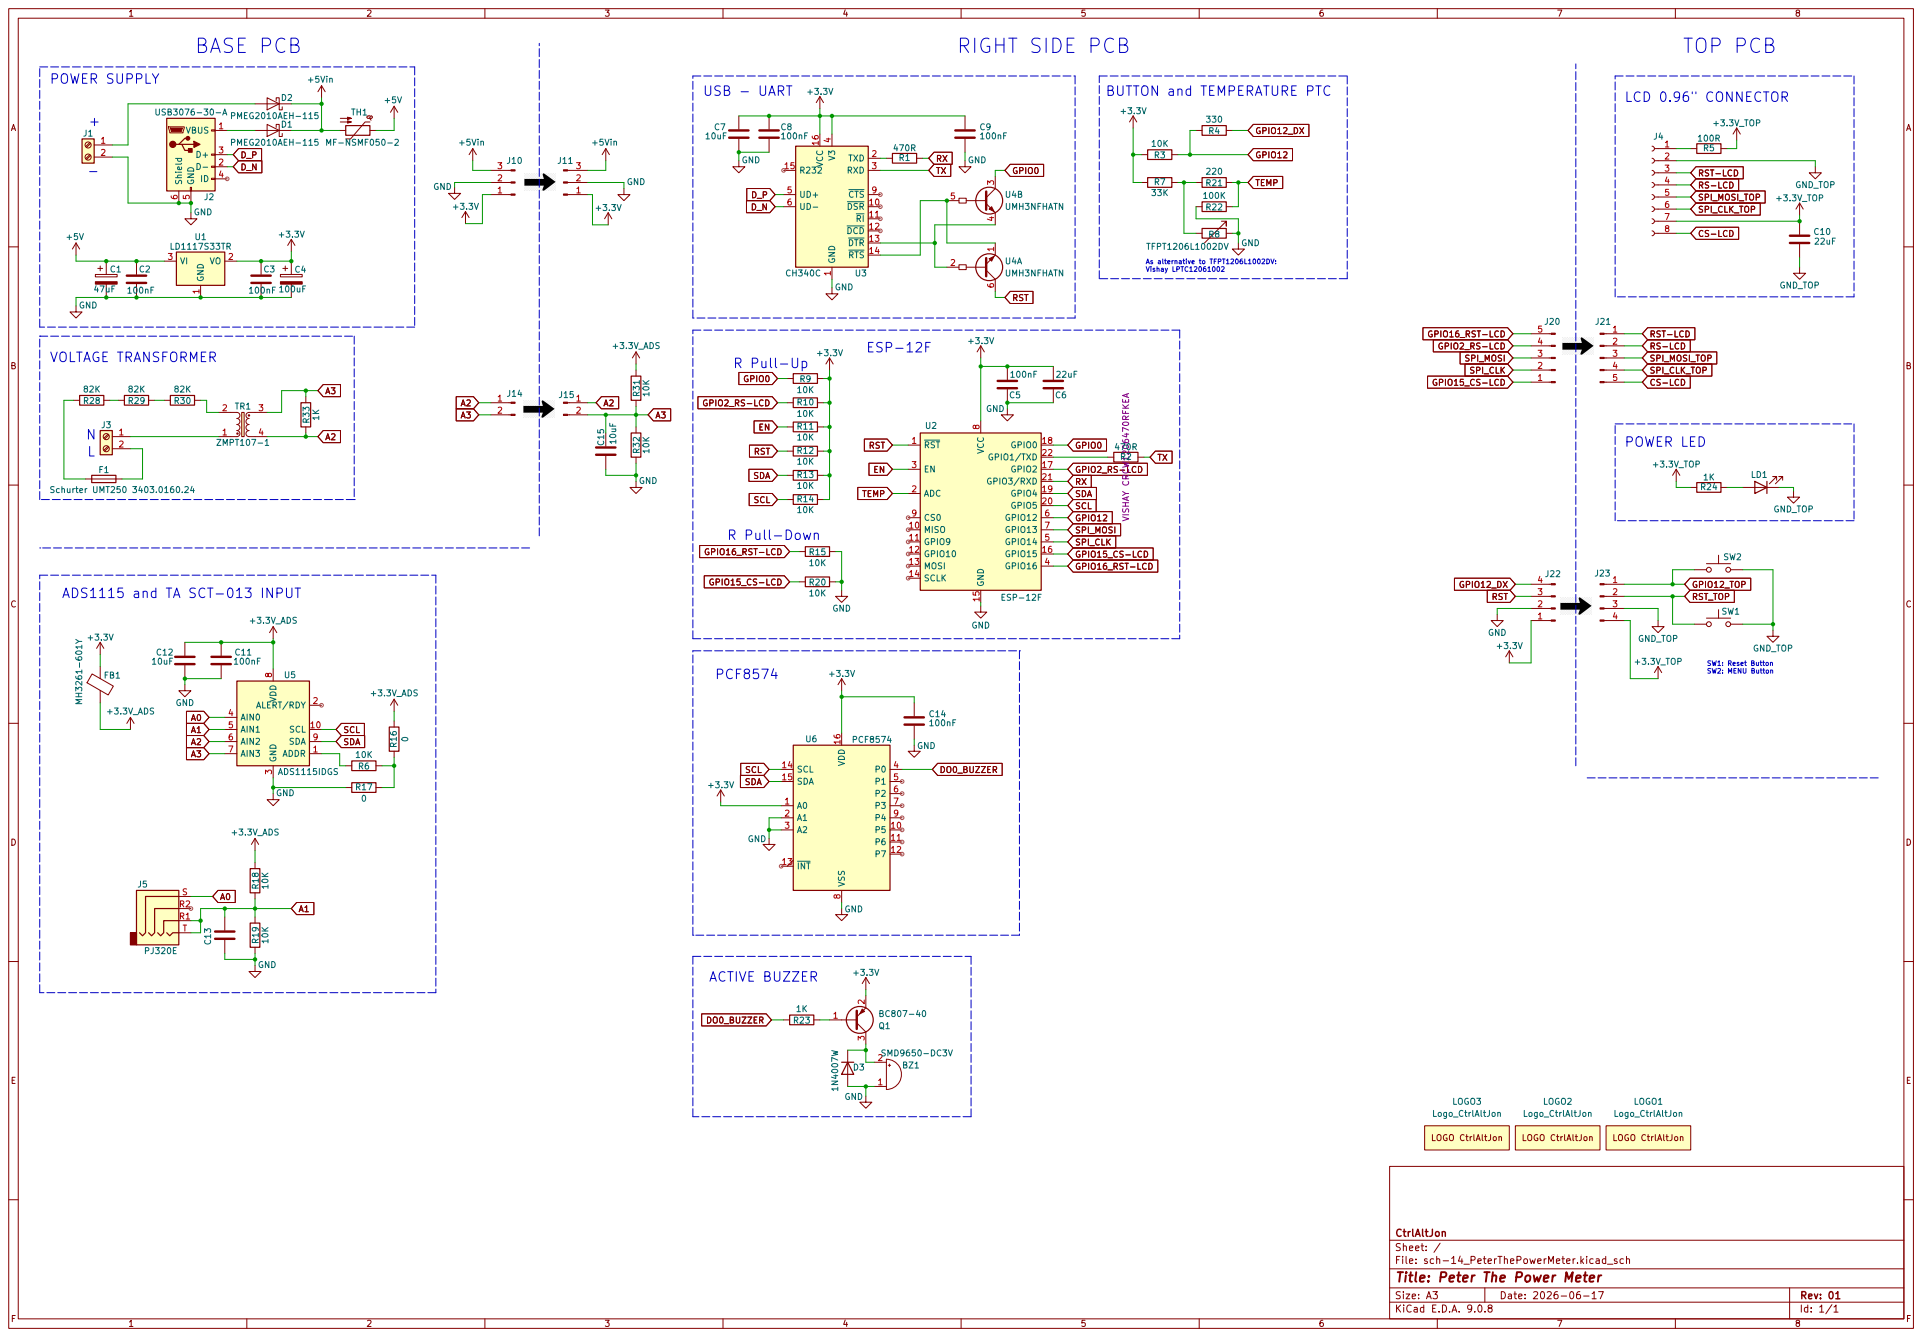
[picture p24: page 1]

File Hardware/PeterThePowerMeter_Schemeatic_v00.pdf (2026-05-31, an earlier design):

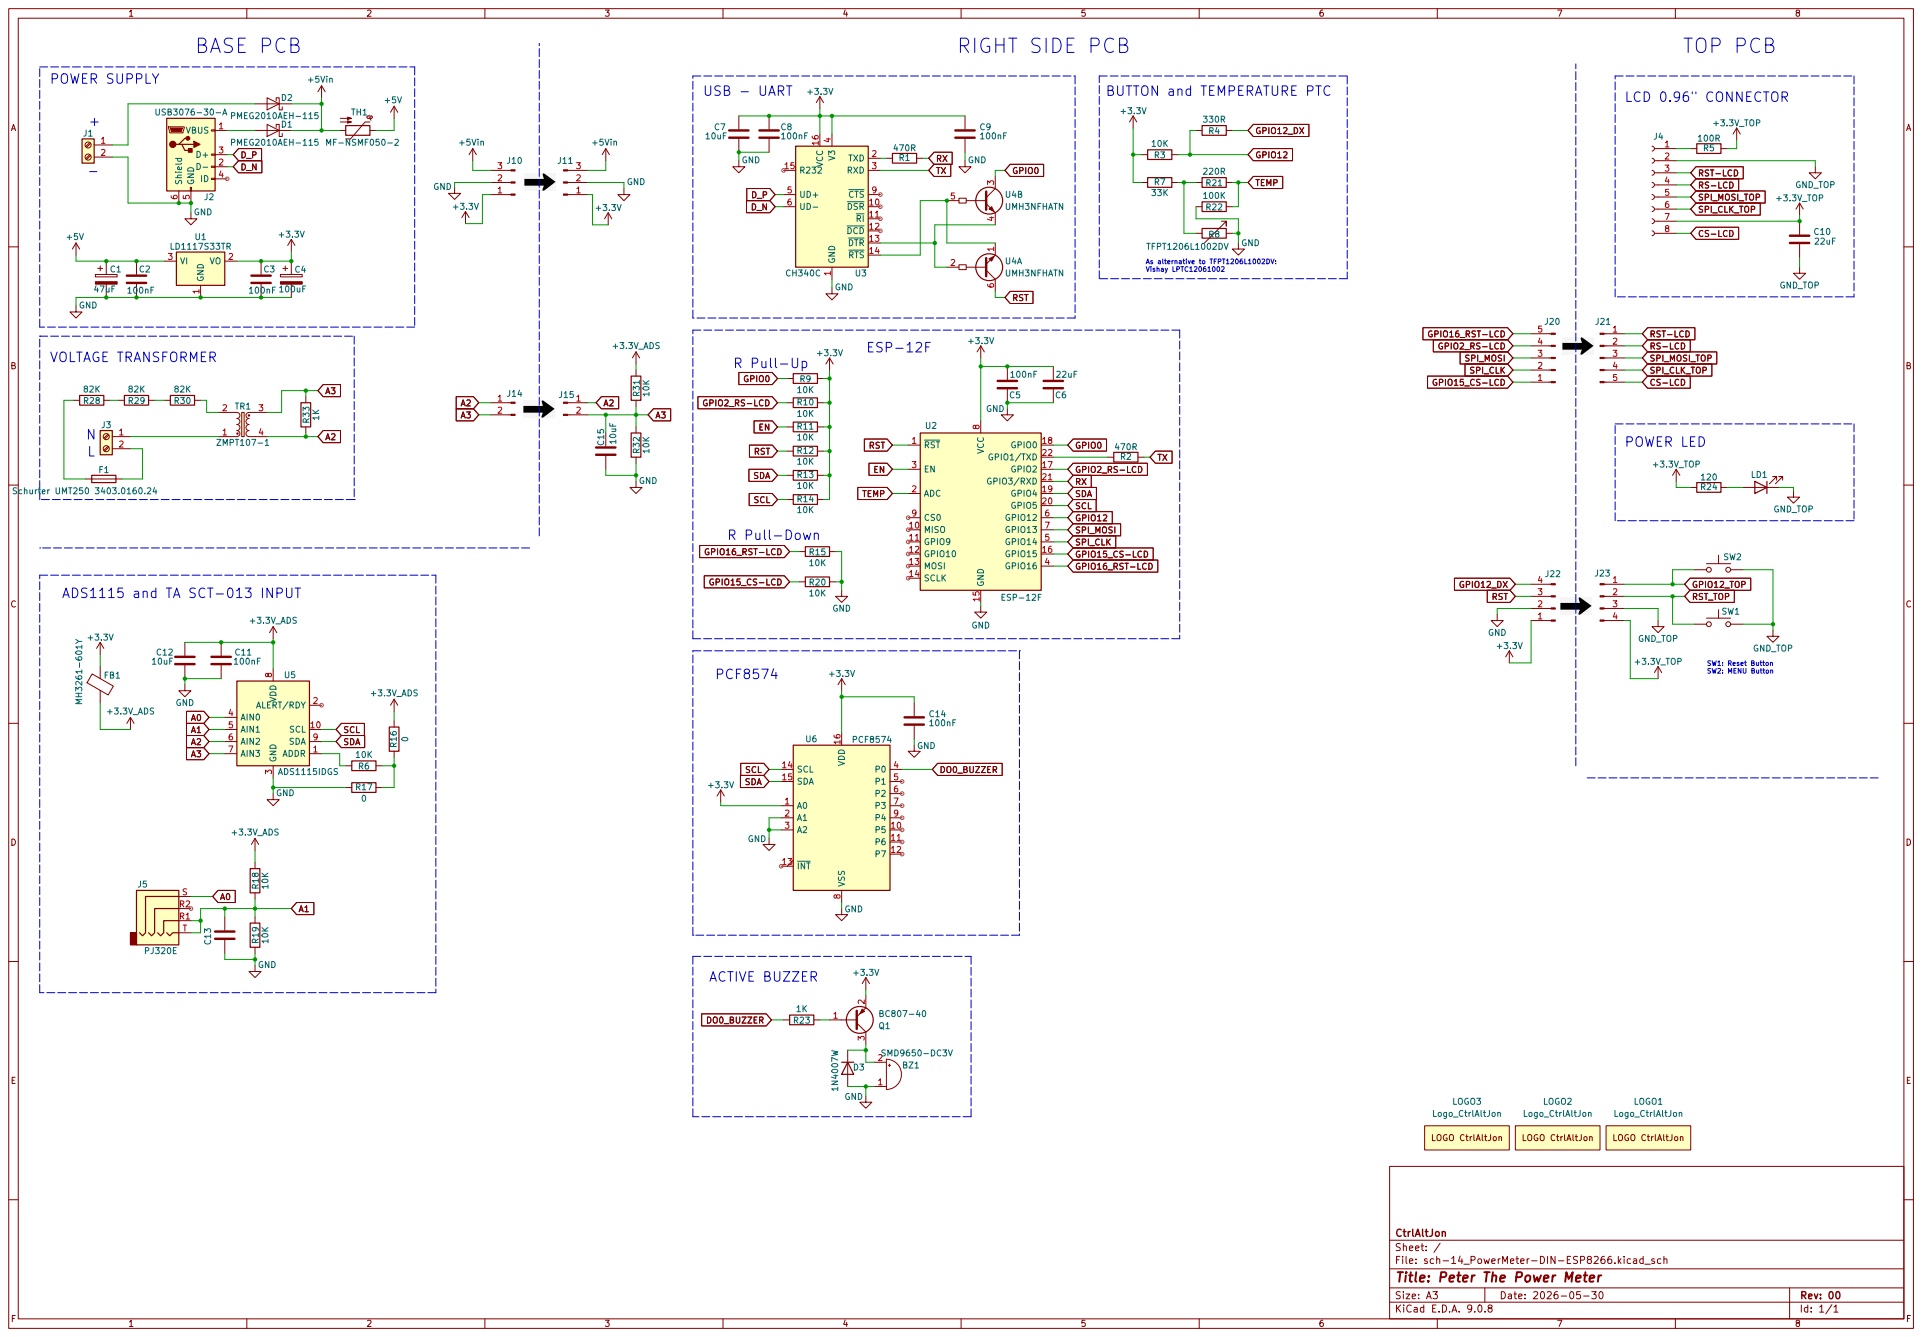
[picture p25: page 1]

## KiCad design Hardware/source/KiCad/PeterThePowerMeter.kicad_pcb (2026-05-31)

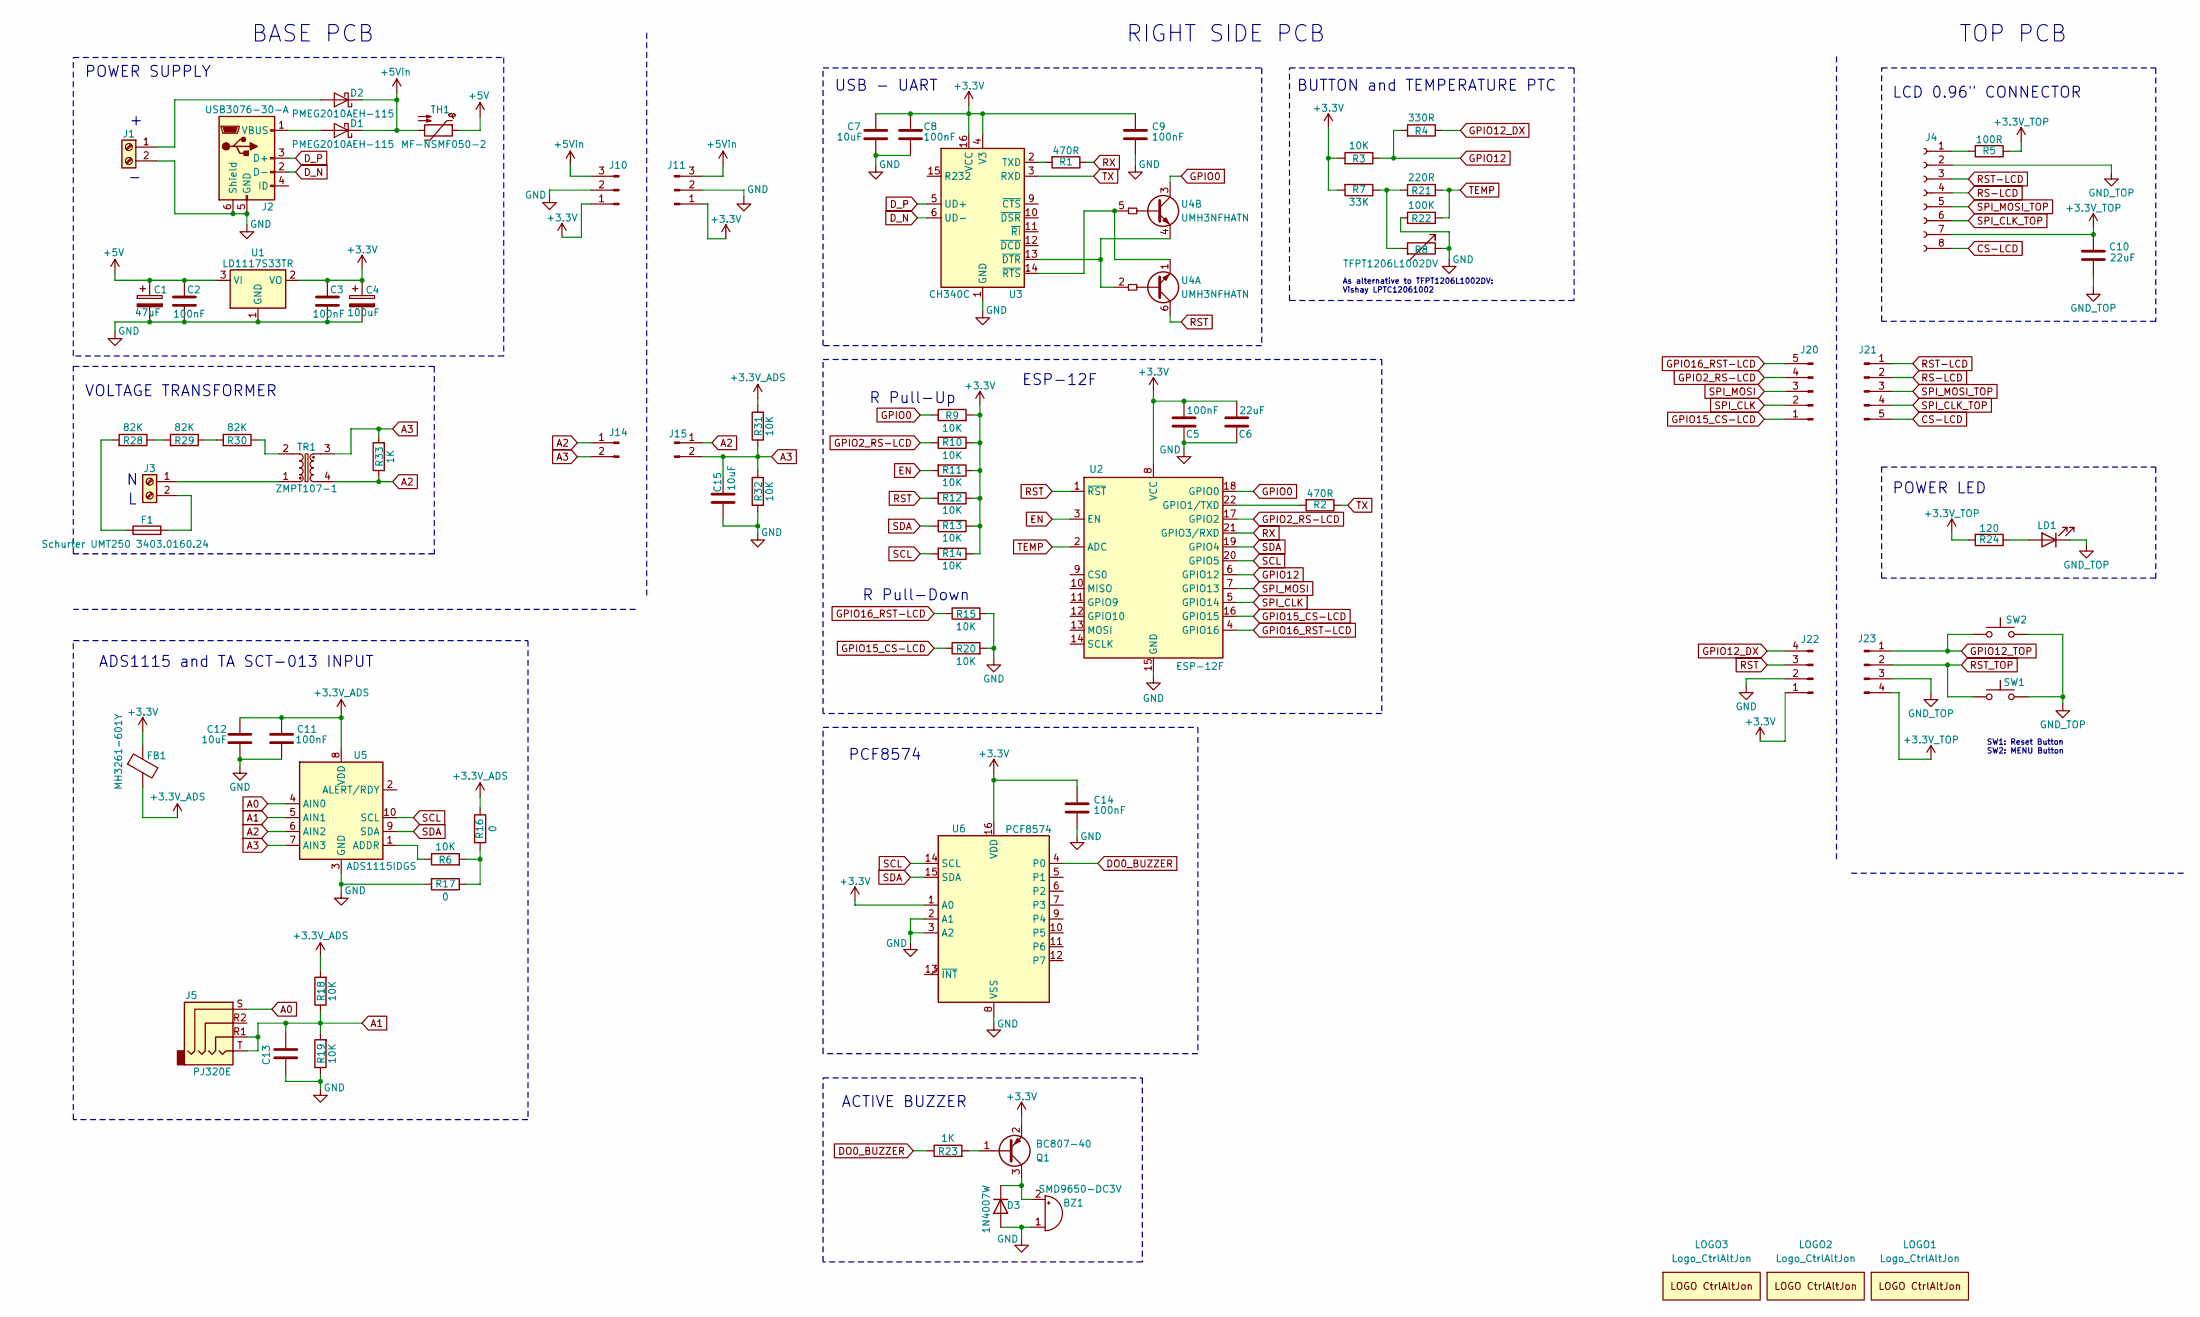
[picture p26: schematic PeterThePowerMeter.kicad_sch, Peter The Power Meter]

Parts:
BZ1: SMD9650-DC3V; Buzzer_CUI_CPT-9019S-SMT
C1: 47uF; CP_Radial_D6.3mm_P2.50mm
C2, C3, C5, C8, C9, C11, C14: 100nF; C_1206_3216Metric_Pad1.33x1.80mm_HandSolder
C4: 100uF; CP_Radial_D6.3mm_P2.50mm
C6, C10: 22uF; C_1206_3216Metric_Pad1.33x1.80mm_HandSolder
C7, C12, C13, C15: 10uF; C_1206_3216Metric_Pad1.33x1.80mm_HandSolder
D1, D2: PMEG2010AEH-115; D_SOD-123F
D3: 1N4007W; D_SOD-123
F1: Schurter UMT250 3403.0160.24; Fuse_Schurter_UMZ250
FB1: MH3261-601Y; L_1206_3216Metric
J1, J3: Screw_Terminal_01x02; PhoenixContact_MSTBA_2,5_2-G_1x02_P5.00mm_Horizontal
J2: USB3076-30-A; USB_Micro-B_GCT_USB3076-30-A
J4: Conn_01x08_Socket; Hirose_FH12-8S-0.5SH_1x08-1MP_P0.50mm_Horizontal
J5: PJ320E; Jack_3.5mm_PJ320E_Horizontal
J10: Conn_01x03_Pin; PinHeader_1x03_P2.54mm_Vertical
J11: Conn_01x03_Pin; PinHeader_1x03_P2.54mm_Horizontal
J14: Conn_01x02_Pin; PinHeader_1x02_P2.54mm_Vertical
J15: Conn_01x02_Pin; PinHeader_1x02_P2.54mm_Horizontal
J20: Conn_01x05_Pin; PinHeader_1x05_P2.54mm_Horizontal
J21: Conn_01x05_Pin; PinHeader_1x05_P2.54mm_Vertical
J22: Conn_01x04_Male; PinHeader_1x04_P2.54mm_Horizontal
J23: Conn_01x04_Male; PinHeader_1x04_P2.54mm_Vertical
LD1: LED; LED_1206_3216Metric
LOGO1, LOGO2, LOGO3: Logo_CtrlAltJon
Q1: BC807-40; SOT-23
R1, R2: 470R; R_1206_3216Metric_Pad1.30x1.75mm_HandSolder
R3, R6, R9, R10, R11, R12, R13, R14, R15, R18, R19, R20, R31, R32: 10K; R_1206_3216Metric_Pad1.30x1.75mm_HandSolder
R4: 330R; R_1206_3216Metric_Pad1.30x1.75mm_HandSolder
R5: 100R; R_1206_3216Metric_Pad1.30x1.75mm_HandSolder
R7: 33K; R_1206_3216Metric_Pad1.30x1.75mm_HandSolder
R8: TFPT1206L1002DV; R_1206_3216Metric_Pad1.30x1.75mm_HandSolder
R16, R17: 0; R_1206_3216Metric_Pad1.30x1.75mm_HandSolder
R21: 220R; R_1206_3216Metric_Pad1.30x1.75mm_HandSolder
R22: 100K; R_1206_3216Metric_Pad1.30x1.75mm_HandSolder
R23, R33: 1K; R_1206_3216Metric_Pad1.30x1.75mm_HandSolder
R24: 120; R_1206_3216Metric_Pad1.30x1.75mm_HandSolder
R28, R29, R30: 82K; R_1206_3216Metric_Pad1.30x1.75mm_HandSolder
SW1: 3.2x4.2; SW_Push_1P1T_NO_Vertical_Wuerth_434133025816
SW2: 434133025816; SW_Push_1P1T_NO_Vertical_Wuerth_434133025816
TH1: MF-NSMF050-2; R_1206_3216Metric_Pad1.30x1.75mm_HandSolder
TR1: ZMPT107-1; Transformer_Zeming_ZMPT107
U1: LD1117S33TR; SOT-223-3_TabPin2
U2: ESP-12F; ESP-12E
U3: CH340C; SOIC-16_3.9x9.9mm_P1.27mm
U4: UMH3NFHATN; SOT-363_SC-70-6
U5: ADS1115IDGS; TSSOP-10_3x3mm_P0.5mm
U6: PCF8574; SOIC-16W_7.5x10.3mm_P1.27mm

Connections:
+3.3V: C3.1, C4.1, C5.1, C6.1, C7.1, C8.1, C9.1, C14.1, FB1.1, J10.1, J11.1, J22.1, Q1.2 (E), R3.2, R7.2, R9.2, R10.1, R11.1, R12.1, R13.1, R14.1, U1.2 (VO), U2.8 (VCC), U3.4 (V3), U3.16 (VCC), U6.1 (A0), U6.16 (VDD)
+3.3V_ADS: C11.2, C12.2, FB1.2, R16.1, R18.2, R31.2, U5.8 (VDD)
+3.3V_TOP: C10.1, J4.7, J23.4, R5.1, R24.2
+5V: C1.1, C2.1, TH1.1, U1.3 (VI)
+5Vin: D1.1 (K), D2.1 (K), J10.3, J11.3, TH1.2
A0: J5.S, U5.4 (AIN0)
A1: C13.2, J5.R1, J5.T, R18.1, R19.2, U5.5 (AIN1)
A2: J14.1, J15.1, R33.1, TR1.4, U5.6 (AIN2)
A3: C15.2, J14.2, J15.2, R31.1, R32.2, R33.2, TR1.3, U5.7 (AIN3)
CS-LCD: J4.8, J21.5
DO0_BUZZER: R23.1, U6.4 (P0)
D_N: J2.2 (D-), U3.6 (UD-)
D_P: J2.3 (D+), U3.5 (UD+)
EN: R11.2, U2.3 (EN)
GND: BZ1.1 (+), C1.2, C2.2, C3.2, C4.2, C5.2, C6.2, C7.2, C8.2, C9.2, C11.1, C12.1, C13.1, C14.2, C15.1, D3.2 (A), J1.2, J2.5 (GND), J2.6 (Shield), J10.2, J11.2, J22.2, R8.1, R15.2, R17.2, R19.1, R20.2, R22.2, R32.1, U1.1 (GND), U2.15 (GND), U3.1 (GND), U5.3 (GND), U6.2 (A1), U6.3 (A2), U6.8 (VSS)
GND_TOP: C10.2, J4.2, J23.3, LD1.1 (K), SW1.2, SW2.2
GPIO0: R9.1, U2.18 (GPIO0), U4.3 (C2)
GPIO2_RS-LCD: J20.4, R10.2, U2.17 (GPIO2)
GPIO12: R3.1, R4.2, U2.6 (GPIO12)
GPIO12_DX: J22.4, R4.1
GPIO12_TOP: J23.1, SW2.1
GPIO15_CS-LCD: J20.1, R20.1, U2.16 (GPIO15)
GPIO16_RST-LCD: J20.5, R15.1, U2.4 (GPIO16)
unnamed: BZ1.2 (-), D3.1 (K), Q1.3 (C)
unnamed: D1.2 (A), J2.1 (VBUS)
unnamed: D2.2 (A), J1.1
unnamed: F1.1, R28.2
unnamed: J3.1, TR1.1
unnamed: F1.2, J3.2
unnamed: J4.1, R5.2
unnamed: LD1.2 (A), R24.1
unnamed: Q1.1 (B), R23.2
unnamed: R6.2, R16.2, R17.1
unnamed: R7.1, R8.2, R21.2
unnamed: R28.1, R29.2
unnamed: R29.1, R30.2
unnamed: R30.1, TR1.2
unnamed: R2.2, U2.22 (GPIO1/TXD)
unnamed: R1.2, U3.2 (TXD)
unnamed: U3.13 (~DTR), U4.2 (B1), U4.4 (E2)
unnamed: U3.14 (~RTS), U4.1 (E1), U4.5 (B2)
unnamed: R6.1, U5.1 (ADDR)
RS-LCD: J4.4, J21.2
RST: J22.3, R12.2, U2.1 (~RST), U4.6 (C1)
RST-LCD: J4.3, J21.1
RST_TOP: J23.2, SW1.1
RX: R1.1, U2.21 (GPIO3/RXD)
SCL: R14.2, U2.20 (GPIO5), U5.10 (SCL), U6.14 (SCL)
SDA: R13.2, U2.19 (GPIO4), U5.9 (SDA), U6.15 (SDA)
SPI_CLK: J20.2, U2.5 (GPIO14)
SPI_CLK_TOP: J4.6, J21.4
SPI_MOSI: J20.3, U2.7 (GPIO13)
SPI_MOSI_TOP: J4.5, J21.3
TEMP: R21.1, R22.1, U2.2 (ADC)
TX: R2.1, U3.3 (RXD)

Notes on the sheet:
ADS1115 and TA SCT-013 INPUT
POWER LED
VOLTAGE TRANSFORMER
USB - UART
ESP-12F
R Pull-Up
PCF8574
BASE PCB
LCD 0.96" CONNECTOR
RIGHT SIDE PCB
R Pull-Down
POWER SUPPLY
ACTIVE BUZZER
As alternative to TFPT1206L1002DV: Vishay LPTC12061002
TOP PCB
SW1: Reset Button SW2: MENU Button
BUTTON and TEMPERATURE PTC

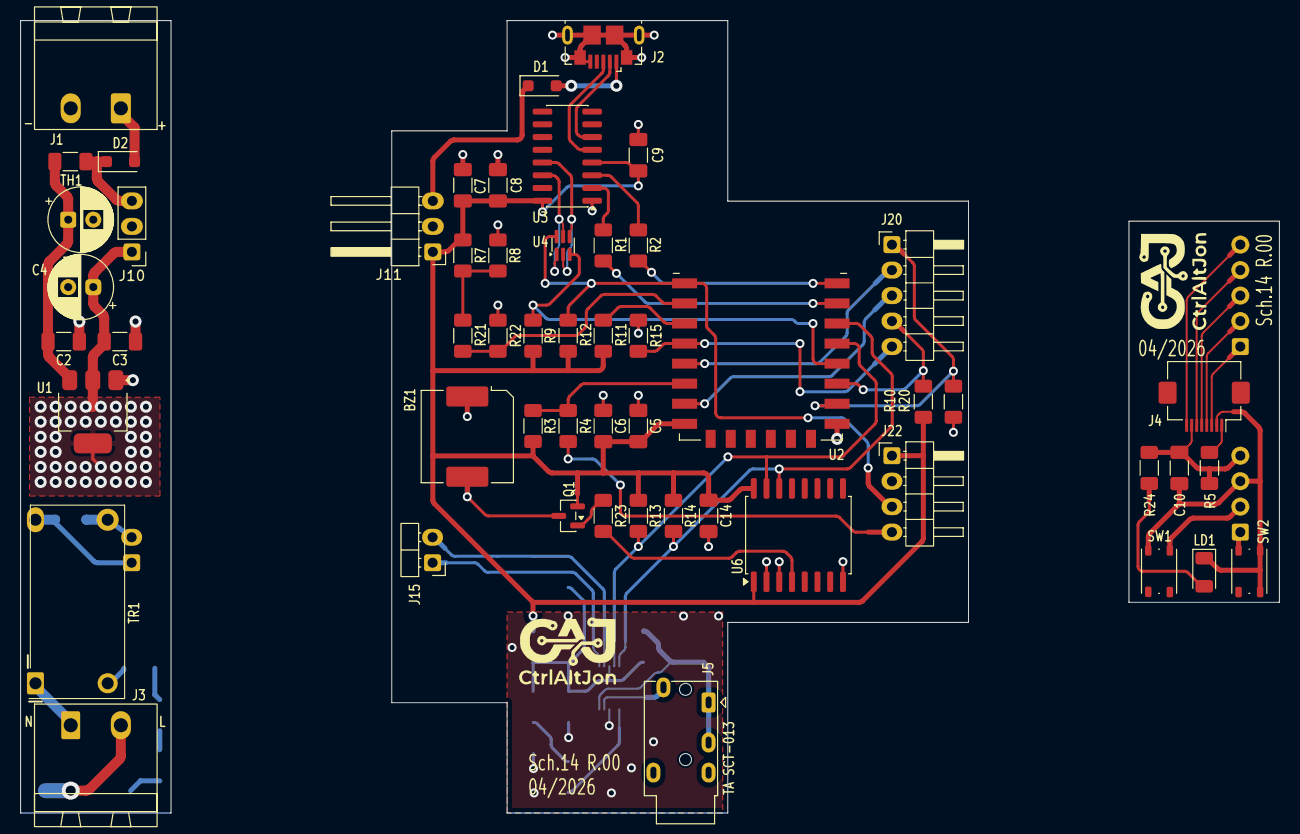
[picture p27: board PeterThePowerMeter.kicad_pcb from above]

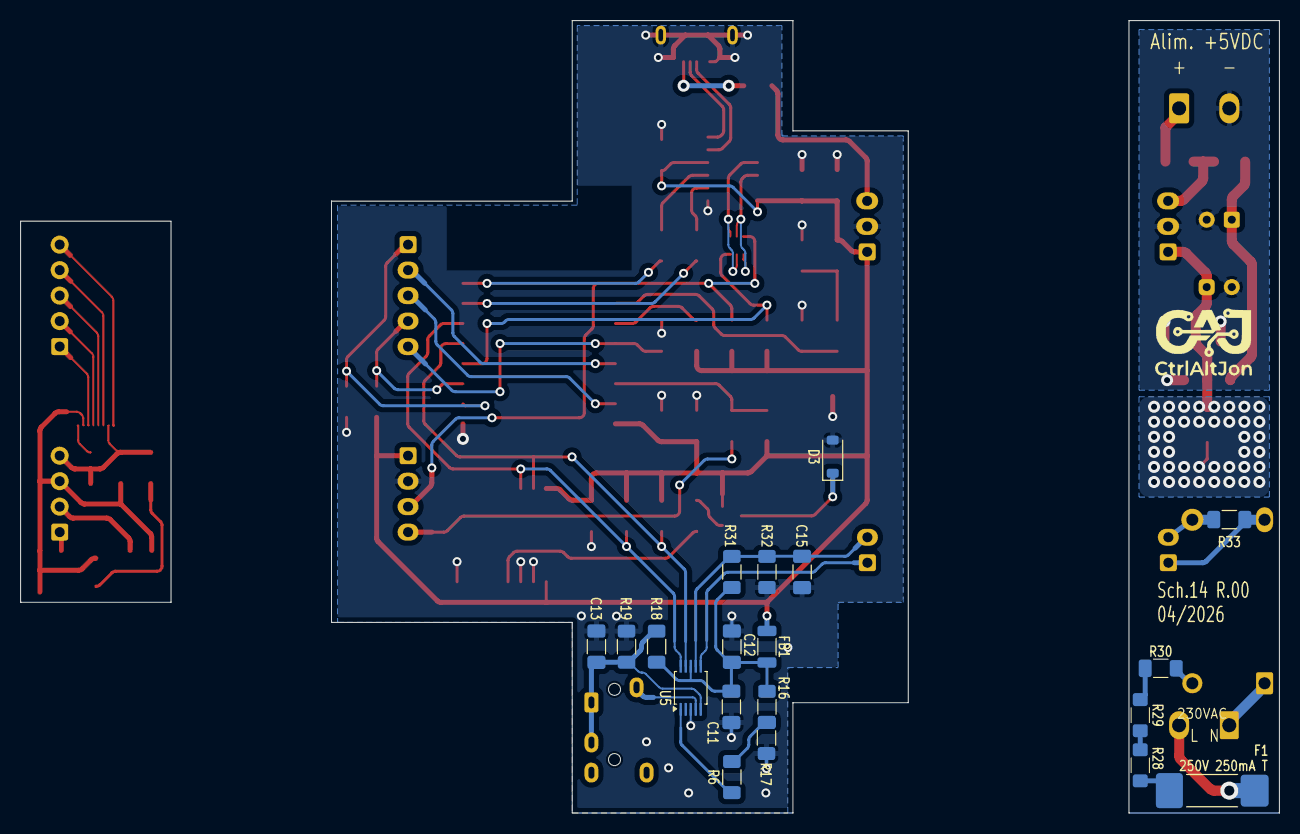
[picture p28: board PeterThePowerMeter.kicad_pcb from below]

Board: 2 copper layers, 125.5 x 79.0 mm, 79 parts (22 on the bottom side), 55 nets.

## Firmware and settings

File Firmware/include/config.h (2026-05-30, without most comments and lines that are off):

#define CONFIG_H
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
#include <Arduino.h>                                                      // Include Arduino core library for basic types and functions
#define FIRMWARE_VERSION         "0.0"                                    // Firmware version string
#define EEPROM_SIZE               1024                                    // EEPROM size in bytes
#define EEPROM_MAGIC              0x4A                                    // Magic byte to validate EEPROM data (ASCII 'J' for Jon)
#define PIN_BTN                   12                                      // Button pin
#define PIN_PTC                   A0                                      // Analog input for PTC
#define PCF8574_ADDR              0x21                                    // I2C address for PCF8574 (Detected by scan)
#define ADS1115_ADDR              0x48                                    // I2C address for ADS1115 (Detected by scan)
#define PCF_BIT_BUZZER            0                                       // Bit index for Buzzer on PCF8574
#define DEBOUNCE_DELAY            100                                     // Button debounce delay
#define HOLD_THRESHOLD            900                                     // Time to hold button for long press (ms)
#define REPEAT_DELAY              350                                     // Delay before repeating action when button is held (ms)
#define SYS_ACTION_HOLD           5000                                    // Time to hold button for system actions (s)
#define PAGE_TIMEOUT              30000                                   // OLED auto-return timeout
#define MQTT_PUBLISH_INTERVAL     20000                                   // Standard publish interval
#define DISPLAY_UPDATE_INTERVAL   500                                     // LCD refresh rate (ms)
#define RMS_WINDOW_MS             1000                                    // RMS window calculation interval (ms)
#define WIFI_CONNECT_TIMEOUT      30000                                   // WiFi connection timeout (ms)
#define MAX_BACKOFF               900000                                  // Max reconnection backoff (15 min)
#define SAVE_MSG_DURATION         2000                                    // Duration of "Saved" popup (ms)
#define UI_SCROLL_DELAY           2000                                    // Pause before text scroll (ms)
#define UI_SCROLL_SPEED           2                                       // Pixels per frame
#define AP_MSG_DURATION           3000                                    // AP Mode confirmation duration (ms)
#define WEB_REFRESH_STATUS        10                                      // Web root refresh (s)
#define WEB_REFRESH_SAVE          2                                       // Web redirect after save (s)
#define WEB_REFRESH_REBOOT        5                                       // Web redirect after reboot (s)
#define DEFAULT_WEB_AUTH_USER     "admin"                                 // Default Basic Auth username
#define DEFAULT_WEB_AUTH_PASS     "admin"                                 // Default Basic Auth password
#define FACTOR_A_V                25.0f                                   // SCT-013 100A/1V factor
#define FACTOR_V_V                246.0f                                  // ZMPT107-1 Voltage divider factor
#define ADS_MULTIPLIER            0.0000625f                              // GAIN_TWO: 2.048V / 32768
#define ADS_GAIN                  GAIN_TWO                                // ADS1115 Gain setting
#define ADS_SPS                   RATE_ADS1115_860SPS                     // ADS1115 Data rate
#define PTC_AVG_SAMPLES           10                                      // Number of PTC samples for averaging
#define TEMP_WARNING_THRESHOLD    45.0f                                   // Temp color change trigger (°C)
#define CURRENT_NOISE_FLOOR       0.002f                                  // Noise floor filter for RMS current calculation
#define VOLTAGE_MIN_THRESHOLD     50.0f                                   // Minimum voltage to use real reading (otherwise fallback to 230V)
#define CAL_SCALE_DEFAULT         1.0f                                    // Default multiplicative scale (no correction)
#define CAL_SCALE_MIN             0.1f                                    // Minimum allowed scale factor
#define CAL_SCALE_MAX             10.0f                                   // Maximum allowed scale factor
#define CAL_OFFSET_V_MIN          -500.0f                                 // Voltage offset limits (V)
#define CAL_OFFSET_V_MAX          500.0f
#define CAL_OFFSET_A_MIN          -100.0f                                 // Current offset limits (A)
#define CAL_OFFSET_A_MAX          100.0f
#define CAL_OFFSET_TEMP_MIN       -50.0f                                  // Temperature offset limits (°C)
#define CAL_OFFSET_TEMP_MAX       50.0f
#define PTC_R_DIVIDER_TOTAL       100220.0f                               // R21 (220) + R22 (100k)
#define PTC_R_DIVIDER_LOAD        100000.0f                               // R22 (100k)
#define PTC_R_PULLUP              33000.0f                                // R7 (33k pull-up to 3.3V)
#define PTC_V_SOURCE              3.3f                                    // Logic source voltage
#define PTC_NOMINAL_RES           10000.0f                                // PTC resistance at 25°C (10k)
#define PTC_COEFF                 0.00411f                                // PTC Temperature Coefficient (TCR)
#define DEFAULT_POWER_THRESHOLD   3100                                    // Default power threshold for alerts (W)
#define MAX_POWER_THRESHOLD       6000                                    // UI wrap-around for power threshold
#define THRESHOLD_STEP            100                                     // UI increment step for power threshold
#define DEFAULT_GRID_VOLTAGE      230                                     // Default grid voltage for power calculation if measurement is invalid (V)
#define DEFAULT_MQTT_PORT         1883                                    // Default MQTT port
#define DEFAULT_MANUFACTURER      "DIY"                                   // Default manufacturer string for device information
#define DEFAULT_HA_PREFIX         "homeassistant"                         // Default Home Assistant discovery prefix
#define MQTT_BUFFER_SIZE          512                                     // MQTT message buffer size
#define MQTT_THRESHOLD_COMMAND_TOPIC "%s/threshold/set"                   // MQTT command topic for power threshold
#define MQTT_BUZZER_MODE_COMMAND_TOPIC "%s/buzzer_mode/set"               // MQTT command topic for buzzer mode
#define MQTT_TIMEOUT              5                                       // MQTT connection timeout (s)
namespace Layout {                                                        // Namespace to encapsulate all layout-related constants and definitions
  const int SCREEN_W              = 80;                                   // Width of the display in pixels
  const int SCREEN_H              = 160;                                  // Height of the display in pixels
  const int SCREEN_CX             = SCREEN_W / 2;                         // Center X
  const uint16_t COL_BLACK        = 0x0000;
  const uint16_t COL_WHITE        = 0xFFFF;
  const uint16_t COL_RED          = 0xF800;
  const uint16_t COL_GREEN        = 0x3666;                               // Custom Green for badges
  const uint16_t COL_BLUE         = 0x001F;
  const uint16_t COL_CYAN         = 0x07FF;
  const uint16_t COL_YELLOW       = 0xFFE0;
  const uint16_t COL_YELLOW_DARK  = 0xFE80;                               // Custom Dark Yellow
  const uint16_t COL_ORANGE       = 0xFD20;
  const uint16_t COL_BG_BADGE_OFF = 0x2965;                               // Dark Gray for OFF badges
  const uint16_t COL_TEXT_UNIT    = 0xBDF7;                               // Light Blue for units (kW)
  const uint16_t COL_INFO_LABEL   = 0x1D58;                               // Dark Blue for info labels (Host, SSID, IP)
  const uint16_t COL_GRAY_TEXT    = 0x9492;                               // Medium Gray for secondary text
  const uint16_t COL_TREND_BLUE   = 0x19D7;                               // Graph line color
  const uint16_t COL_TREND_CYAN   = 0x433E;                               // Graph current value point color
  const int BADGE_W               = 38;                                   // Badges width
  const int BADGE_H               = 20;                                   // Badges height
  const int BADGE_SPACING         = 2;                                    // Spacing between badges
  const int BADGE_GROUP_W         = (BADGE_W * 2) + BADGE_SPACING;        // Total width of the group of badges (WiFi + MQTT + spacing)
  const int BADGE_WIFI_X          = (SCREEN_W - BADGE_GROUP_W) / 2;       // X coordinate to center the group of badges
  const int BADGE_MQTT_X          = BADGE_WIFI_X + BADGE_W + BADGE_SPACING;    // X coordinate for the MQTT badge
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

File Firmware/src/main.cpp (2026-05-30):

// ###########################################################################################################################
// This code is for a Power Meter using ESP8266 (ESP12-F), ADS1115 ADC, LCD color display 0.96", and MQTT communication.
// It measures current using a current transformer (SCT-013), measures voltage using a voltage sensor transformer ZMPT107-1
// and calculates power consumption.
// It also uses MQTT to send data to a broker.
// It has a web interface to configure the device configuration.
//
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
// ###########################################################################################################################

// Include Libraries
#include <Arduino.h>                                                      // Main Arduino Library
#include <Wire.h>                                                         // I2C Library
#include <Adafruit_ADS1X15.h>                                             // ADS1115 Library
#include <ESP8266WiFi.h>                                                  // WiFi Library for ESP8266
#include <WiFiUdp.h>                                                      // WiFi UDP Library
#include <PubSubClient.h>                                                 // MQTT Library
#include <ESP8266WebServer.h>                                             // Web Server Library for ESP8266
#include <Updater.h>                                                      // OTA Update Library
#include <EEPROM.h>                                                       // EEPROM Library
#include "config.h"                                                       // Master Configuration
#include "languages.h"                                                    // Language definitions
#include "webpages.h"                                                     // Web interface functions
#include "sys_globals.h"                                                  // Global structures
#include "display_manager.h"                                              // Display Manager

// ###########################################################################################################################
//   FUNCTIONS #############################################################################################################
// #######################################################################################################################

// --- Function Prototypes (Index of main logic) ---
void mqttCallback(char* topic, uint8_t* payload, unsigned int length);    // MQTT message callback function
bool pcfWrite();                                                          // Write the output byte to the PCF8574 I/O expander
void wifiStartAP();                                                       // Start the ESP in Access Point mode
void deviceFactoryReset();                                                // Perform a factory reset by erasing EEPROM and restarting the device
void wifiSetup();                                                         // Manage WiFi connection initialization
void mqttPublishDiscovery();                                              // Publishes MQTT discovery messages for Home Assistant auto-discovery
bool mqttReconnect();                                                     // Reconnect to MQTT broker if the connection is lost
void deviceHandleButtons();                                               // Handle button presses and update the display accordingly
void makeMqttSafeId(const char* input, char* output, size_t outputSize);  // Build a MQTT-safe identifier from device_name

// Build a stable MQTT-safe identifier from an arbitrary device name.
void makeMqttSafeId(const char* input, char* output, size_t outputSize) {
  if (outputSize == 0) return;
  size_t oi = 0;

  for (size_t i = 0; input[i] != '\0' && oi < outputSize - 1; i++) {
    char c = input[i];
    bool isLower = (c >= 'a' && c <= 'z');
    bool isUpper = (c >= 'A' && c <= 'Z');
    bool isDigit = (c >= '0' && c <= '9');
    bool isSafe = isLower || isUpper || isDigit || c == '_' || c == '-';

    output[oi++] = isSafe ? c : '_';
  }

  if (oi == 0) {
    strncpy(output, "PwrMtr", outputSize - 1);
    output[outputSize - 1] = '\0';
    return;
  }

  output[oi] = '\0';
}

// ------------------------------------------------------------------------------------------------------------- MQTT Callback
// This function is called when a message is received on a subscribed MQTT topic.
// It parses the incoming message to update the device's configuration (power threshold or buzzer mode)
// based on commands from Home Assistant or other MQTT clients.
void mqttCallback(char* topic, uint8_t* payload, unsigned int length) {
  Serial.print("MQTT Message arrived [");
  Serial.print(topic);
  Serial.print("] ");
  char message_buff[MQTT_BUFFER_SIZE];
  size_t copyLen = (length < (sizeof(message_buff) - 1)) ? length : (sizeof(message_buff) - 1);
  memcpy(message_buff, payload, copyLen);
  message_buff[copyLen] = '\0';
  if (length >= sizeof(message_buff)) {
    Serial.printf("MQTT payload truncated: %u -> %u bytes\n", length, (unsigned int)copyLen);
  }
  Serial.println(message_buff);

  char threshold_cmd_topic[128];
  char buzzer_cmd_topic[128];
  char mqttDeviceId[33];
  makeMqttSafeId(sysConfig.device_name, mqttDeviceId, sizeof(mqttDeviceId));
  snprintf(threshold_cmd_topic, sizeof(threshold_cmd_topic), MQTT_THRESHOLD_COMMAND_TOPIC, mqttDeviceId);
  snprintf(buzzer_cmd_topic, sizeof(buzzer_cmd_topic), MQTT_BUZZER_MODE_COMMAND_TOPIC, mqttDeviceId);

  bool config_changed = false;

  if (strcmp(topic, threshold_cmd_topic) == 0) {
    int newThreshold = atoi(message_buff);
    if (newThreshold >= 0 && newThreshold <= MAX_POWER_THRESHOLD) { // Basic validation
      if (sysConfig.powerThreshold != newThreshold) {
        sysConfig.powerThreshold = newThreshold;
        config_changed = true;
        Serial.printf("Updated powerThreshold to %d\n", newThreshold);
      }
    } else {
      Serial.printf("Invalid powerThreshold value received: %s\n", message_buff);
    }
  } else if (strcmp(topic, buzzer_cmd_topic) == 0) {
    BuzzerMode newMode = BUZZER_MODE_COUNT; // Using COUNT as invalid/null value
    
    if (strcmp_P(message_buff, (PGM_P)getText(ID_BUZZER_MODE_CONTINUOUS)) == 0) newMode = BUZZER_MODE_CONTINUOUS;
    else if (strcmp_P(message_buff, (PGM_P)getText(ID_BUZZER_MODE_PULSE_SLOW)) == 0) newMode = BUZZER_MODE_PULSE_SLOW;
    else if (strcmp_P(message_buff, (PGM_P)getText(ID_BUZZER_MODE_PULSE_FAST)) == 0) newMode = BUZZER_MODE_PULSE_FAST;

    if (newMode != BUZZER_MODE_COUNT && sysConfig.buzzerMode != newMode) {
      sysConfig.buzzerMode = newMode;
      config_changed = true;
      Serial.printf("Updated buzzerMode to %d\n", (int)newMode);
    } else if (newMode == BUZZER_MODE_COUNT) {
      Serial.printf("Invalid buzzerMode value received: %s\n", message_buff);
    }
  }

  if (config_changed) {
    EEPROM.put(1, sysConfig);
    if (EEPROM.commit()) { savedSysConfig = sysConfig; Serial.println("Configuration saved to EEPROM from MQTT."); }
    else { Serial.println("Failed to save configuration to EEPROM from MQTT."); }
    lastDisplayUpdate = 0; // Force display update if needed
  }
}

// ---------------------------------------------------------------------------------------------------------- Write to PCF8574
// Send the status By te to the PCF8574 I/O expander. The byte is inverted before sending to match the active LOW logic of the hardware.
bool pcfWrite() {                                                         // Returns true if transmission is successful
  Wire.beginTransmission(PCF8574_ADDR);
  Wire.write(~pcfOutputByte);                                             // Invert the byte for the PCF8574 logic (active LOW)
  byte error = Wire.endTransmission();                                    // Check for I2C transmission errors
  if (error != 0) {
    Serial.printf("PCF8574: I2C error %d at address 0x%02X\n", error, PCF8574_ADDR);
    return false; // Indicate failure
  }
  return true; // Indicate success
}
// ------------------------------------------------------------------------------------------------------------- Start AP Mode
// ---------------------------------------------------------------------------------------------------------------------------
// Starts the WiFi Access Point mode with an SSID based on the device's MAC address. This is used when no WiFi credentials are
// configured or when user press button to manually start AP mode, allowing the user to connect to the AP and configure the
// device through the web interface.
void wifiStartAP() {
  Serial.println(F("Starting Access Point..."));
  WiFi.mode(WIFI_AP);                                                     // Set WiFi to Access Point mode
  uint8_t mac[6];                                                         // Variable to hold the MAC address bytes
  WiFi.macAddress(mac);                                                   // Get the MAC address of the device
  // Create a unique SSID for the Access Point using the last three bytes of the MAC address (e.g., "PwrMtr-1A2B3C")
  snprintf(sysState.apSSID, sizeof(sysState.apSSID), "PwrMtr-%02X%02X%02X", mac[3], mac[4], mac[5]);
  WiFi.softAP(sysState.apSSID);                                           // Start the Access Point with the generated SSID
  Serial.print(F("AP Started. SSID: ")); Serial.println(sysState.apSSID);
  Serial.print(F("IP Address: ")); Serial.println(WiFi.softAPIP());
}

// ------------------------------------------------------------------------------------------------------------- Factory Reset
// ---------------------------------------------------------------------------------------------------------------------------
// Performs a factory reset by erasing the EEPROM and restarting the device. This is triggered when the user selects the Reset
// option. It ensures that all user configurations are cleared and the device is returned to its initial state.
void deviceFactoryReset() {
  initBootScreen();                                                       // Initialize the boot screen
  addBootMessage("Reset ", BOOT_WARN);                                    // Display a warning message about the reset process
  Serial.println("Factory Reset: Erasing EEPROM...");
  for (int i = 0; i < EEPROM_SIZE; i++) {                                 // Loop through the entire EEPROM
    EEPROM.write(i, 0);                                                   // and write 0 to each byte to clear it
  }
  EEPROM.commit();                                                        // Commit the changes to ensure they are saved
  addBootMessage("Erasing... ", BOOT_OK);                                 // Display a message indicating that the EEPROM is being erased
  delay(1000);
  ESP.restart();                                                          // Restart the device to complete the factory reset process
}
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
void loop() {
  unsigned long now = millis();                                           // Capture current time at the very beginning of the loop

  if (shouldReboot) {                                                     // Handle reboot request
    delay(2000);                                                          // Short delay to allow any pending operations to complete before rebooting
    ESP.restart();                                                        // Restart the device to complete the reboot process
  }

  webServer.handleClient();                                               // Handle incoming web server clients (non-blocking)

  // Naked Block for WiFi and MQTT Reconnection with exponential Backoff Strategy.
  // If WiFi is connected but MQTT is not, it also attempts to reconnect to the MQTT broker using the same backoff strategy.
  {
    int wifiStatus = WiFi.status();                                       // Get the current WiFi connection status

    if (wifiStatus == WL_CONNECTED && lastKnownWifiStatus != WL_CONNECTED) {   // If WiFi just reconnected
      currentBackoff = 5000;                                              // Reset backoff to initial value
      lastReconnectAttempt = 0;                                           // Reset last reconnect attempt time to allow immediate MQTT reconnection attempt
      Serial.println("WiFi Reconnected, resetting backoff.");
    }
    lastKnownWifiStatus = wifiStatus;                                     // Update the last known WiFi status for the next iteration

    if (wifiStatus != WL_CONNECTED && WiFi.getMode() != WIFI_AP) {        // If WiFi is disconnected and device is not in AP mode
      if (now - lastReconnectAttempt > currentBackoff) {                  // Try to reconnect if the backoff time has passed since the last attempt
        lastReconnectAttempt = now;                                       // Update the last reconnect attempt time to the current time
        Serial.print("Reconnecting to WiFi... (Backoff: "); Serial.print(currentBackoff/1000); Serial.println("s)");
        WiFi.begin(sysConfig.ssid, sysConfig.password);                   // Attempt to reconnect to WiFi with the configured SSID and password
        if (currentBackoff < MAX_BACKOFF) currentBackoff *= 2;            // If the connection attempt fails, the backoff time will be doubled
                                                                          // for the next attempt, up to a maximum limit defined by MAX_BACKOFF
      }
    } else if (wifiStatus == WL_CONNECTED) {                              // If WiFi is connected, check MQTT connection
      if (!mqttClient.connected()) {                                      // If MQTT is not connected, attempt to reconnect using the same backoff strategy
        if (now - lastReconnectAttempt > currentBackoff) {                // Try to reconnect if the backoff time has passed since the last attempt
          lastReconnectAttempt = now;                                     // Update the last reconnect attempt time to the current time
          Serial.print("Reconnecting to MQTT... (Backoff: "); Serial.print(currentBackoff/1000); Serial.println("s)");
          if (mqttReconnect()) {                                          // If MQTT reconnection is successful
            currentBackoff = 5000;                                        // If MQTT connection is successful, reset backoff to initial value
            lastReconnectAttempt = 0;                                     // Reset last reconnect attempt time
          } else {                                                        // If MQTT reconnection fails
            if (currentBackoff < MAX_BACKOFF) currentBackoff *= 2;        // The backoff time will be doubled for the next attempt
                                                                          // up to a maximum limit defined by MAX_BACKOFF
          }
        }
      } else {                                                            // If MQTT is connected
        mqttClient.loop();                                                // Call the MQTT client loop to maintain the connection
        if (currentBackoff > 5000) currentBackoff = 5000;                 // Reset backoff
      }
    }
  }

  deviceHandleButtons();                                                  // Handle button input with debounce and hold logic

  // --- Auto-return to Page 1 ---
  // If the current display page is not 1 and the button is not being pressed and if the timeout has elapsed,
  // automatically return to page 1 and hide any save messages
  if (sysState.displayPage != 1 && btnState == HIGH && (now - lastDebounceTime > PAGE_TIMEOUT)) {
    sysState.displayPage = 1;
    sysState.showSaveMessage = false;
  }

  // Differential sampling on ADS1115 for both Current (Ch 0-1) and Voltage (Ch 2-3).
  // The loop processes both measurements at a high rate to ensure accurate RMS values over the 1s calculation window.
  if (ads_ok) {
    // Sample Current (Ch 0-1)
    int16_t resI = ads.readADC_Differential_0_1();
    float vI = (float)resI * ADS_MULTIPLIER;                              // Use centralized multiplier
    sumSamplesI += vI;
    sumSquaredI += (double)vI * vI;

    // Sample Voltage (Ch 2-3)
    int16_t resV = ads.readADC_Differential_2_3();
    float vV = (float)resV * ADS_MULTIPLIER;                              // Use centralized multiplier
    sumSamplesV += vV;
    sumSquaredV += (double)vV * vV;

    samplesCount++;
  }

  // Perform RMS calculation and update power state every second based on the accumulated samples. The RMS calculation also includes a noise filter to ignore very low voltage readings that are likely just noise, and it updates the system state with the calculated current and power values
  if (now - lastSample >= RMS_WINDOW_MS) {                                // Use config.h interval
    unsigned long dt = now - lastSample;                                  // Calculate the time difference since the last sample
    lastSample = now;                                                     // Update the last sample time to the current time
    if (samplesCount > 0) {
      // Current RMS calculation
      double meanI = sumSamplesI / samplesCount;
      double varI = (sumSquaredI / samplesCount) - (meanI * meanI);
      float vRmsI = (varI > 0) ? (float)sqrt(varI) : 0.0f;
      if (vRmsI < CURRENT_NOISE_FLOOR) vRmsI = 0.0f;                      // Use config.h noise floor
      sysState.currentRMS = (vRmsI * FACTOR_A_V * sysConfig.calScaleA) + sysConfig.calOffsetA;
      if (sysState.currentRMS < 0.0f) sysState.currentRMS = 0.0f;

      // Voltage RMS calculation
      double meanV = sumSamplesV / samplesCount;
      double varV = (sumSquaredV / samplesCount) - (meanV * meanV);
      float vRmsV = (varV > 0) ? (float)sqrt(varV) : 0.0f;
      float measuredV = (vRmsV * FACTOR_V_V * sysConfig.calScaleV) + sysConfig.calOffsetV;
      if (measuredV < 0.0f) measuredV = 0.0f;
      
      // Dynamic voltage management: use measurement if valid, otherwise fallback to nominal
      measuredVoltageRMS = (measuredV > VOLTAGE_MIN_THRESHOLD) ? measuredV : (float)DEFAULT_GRID_VOLTAGE;

      // Calculate Power using real-time measured voltage
      sysState.powerW = sysState.currentRMS * measuredVoltageRMS;
    } else {
      // No samples collected (e.g. ADS1115 missing or hardware error)
      sysState.currentRMS = 0.0f;
      sysState.powerW = 0.0f;
      measuredVoltageRMS = 0.0f;                                          // No sensor = 0V
    }

    // --- PTC Temperature Measurement (Averaged over 10 cycles) ---
    sysState.ptcSum += analogRead(PIN_PTC);                               // Use global state accumulator
    sysState.ptcCount++;                                                  // Use global state counter
    if (sysState.ptcCount >= PTC_AVG_SAMPLES) {                           // Use config.h constant
      float avgRaw = sysState.ptcSum / (float)PTC_AVG_SAMPLES;
      // Voltage measured at the ADC pin. 1.0V reference for bare ESP8266
      float vMeasuredADC = avgRaw * (1.0 / 1023.0);
      // Recover voltage at the main divider junction by compensating the drop across R21 (220 ohm) due to R22 (100k) load
      // V_main_divider = V_ADC * (R21 + R22) / R22
      float vDivider = vMeasuredADC * (PTC_R_DIVIDER_TOTAL / PTC_R_DIVIDER_LOAD);
      const float kEpsilon = 0.001f;                                          // Small guard to avoid near-zero denominators
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

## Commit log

2026-05-30 Update Hardware files
    [PeterThePowerMeter-B_Cu.gbl, PeterThePowerMeter-B_Fab.gbr, PeterThePowerMeter-B_Mask.gbs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]
2026-05-31 Added LCD to BOM
    [PeterThePowerMeter_BOM.ods]
2026-05-31 Uploaded hardware files and schematic
    [PeterThePowerMeter-B_Cu.gbl, PeterThePowerMeter-B_Fab.gbr, PeterThePowerMeter-B_Mask.gbs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]
2026-05-31 Updated BOM CH340G -> CH340C
    [PeterThePowerMeter_BOM.ods]
2026-06-17 Released 01 version
    [PeterThePowerMeter-B_Cu.gbl, PeterThePowerMeter-B_Fab.gbr, PeterThePowerMeter-B_Mask.gbs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]

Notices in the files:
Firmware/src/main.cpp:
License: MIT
